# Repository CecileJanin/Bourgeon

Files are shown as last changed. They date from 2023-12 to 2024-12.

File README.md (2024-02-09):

# Bourgeon - A fully open source SBC based on i.MX6Q

Bourgeon is a single board computer based on [i.MX6Q](https://www.nxp.com/products/processors-and-microcontrollers/arm-processors/i-mx-applications-processors/i-mx-6-processors/i-mx-6quad-processors-high-performance-3d-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), a quad-core arm cortex A9 processor with 2Go of DDR3 RAM.
This project has been realised for learning purposes only.

_**A developpement board is functionnal, after applying hardware patches.**_

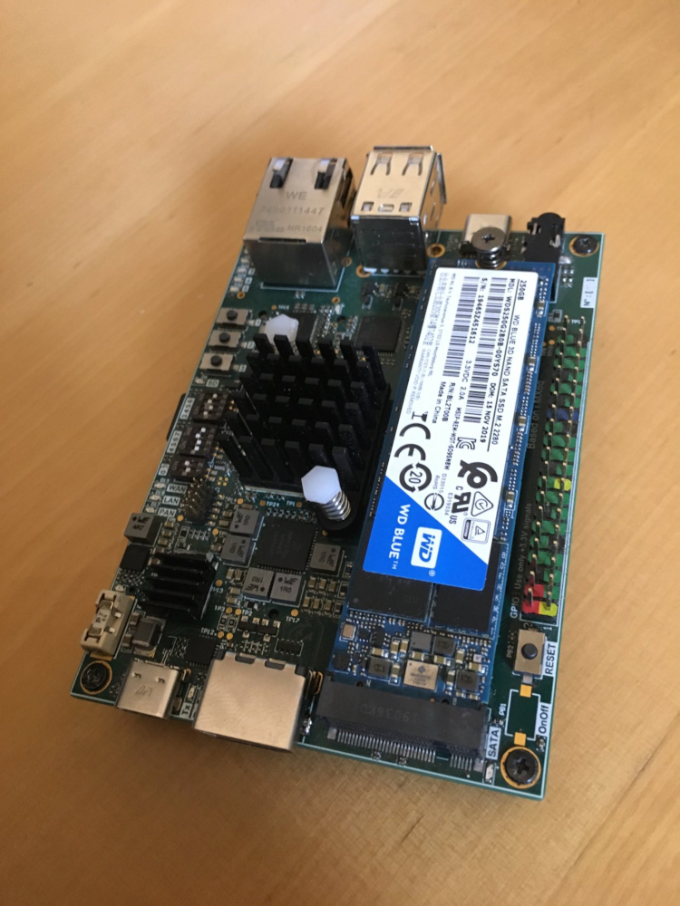
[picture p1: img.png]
bourgeon


## Hardware specification

#### Connectivity :
- 2 USB type A ports
- 1 USB type C OTG port 
- 1 RJ45 10/100/1000 BASE-T ethernet
- 1 M.2 SATA connector 
- 1 SD card slot
- 1 HDMI port
- 1 GPIO raspberry pi compatible connector
- 1 USB type C debug and power port
- 1 mPCIe (with sim card available)
- 1 audio jack 3.5mm
- M.2 non-standard board to board connector, with UART, CAN, SPI, eMMC 8bits, I2C, GPIO...

#### Included memory :
- 8MB Flash NOR via SPI
- 64kB Eeprom via I2C
- 2GB DDR3 RAM 64 bits

## Software

Check boot log file for more detais.

#### Boot

This board uses [u-boot](https://www.denx.de/project/u-boot/), the sources files will be available in src/uboot.

#### linux kernel

The entire board image is under development, and not all hardware is currently supported.

Working and tested :
- RAM
- Sata
- mPCIe
- USB Host
- USB debug
- SD card slot
- Ethernet 10/100/1000BASE-T
- Audio codec SGTL500 
- And some miscellaneous function like DVFS, etc...

## Errata

Criticity level :

1 - Board can't work at all - critical

2 - Board function non-operational

3 - Board or board function must be improved

4 - Minor modification needed

- 1 p7 : Differential main ram clock signals DRAM_CLKO_N inverted 
- 1 global : No boot at ambient temperature, but work perfectly after a warm-up time (1min). Cold boot work (-10°C), but board hangs when the temperature is near 20°C 
- 2 p16 : UART TxD and RxD inverted, debug UART can't work properly
- 2 p16/p5 : USB D+ and D- pin inverted, debug UART can't work properly
- 3 p16 : CP2102N is switched off when the reset PB is pressed. Power supply must be changed to +5V except VIO, must be powered from +3.3V_DEBUG
- 3 global : For a full load, the CPU temperature can rise up to 90°C (too much)
- 3 p16 : CTS and RTS must be functional
- 3 p10 : GPIO wrong power domain, gpio 25, 23, 10, 26 are 2,5V instead of 3.3V
- 3 p8 : Bad phy reference ! No documentation about how to change the output clock from 25MHz to 125MHz, finally found solution on texas forum, but it's a non-standard solution !!! Thanks Ti !  
- 4 p7 : Readability, design note "not used" is at the wrong place
- 4 p1 : Readability, Table of content must be improved, more coherent order, add color...
- 4 p4 : Readability, PMIC schemtic must be more readable
- 4 p7 : Readability, decoupling capacitors name is not readable
- 4 p16 : Need two "No ERC" for U12 p18-19
- 4 global : link between pages (yellow arrows with net name) have no up to date location
- 4 global : Net color must be included in pdf files for more readability
- 4 p18 : R174 is too low, must be 1kOhm
- 4 p16 : usb lanes to usb connector routing pattern must be improved
- 4  global : Change ESD diode for generic 0402 package
- 4 p5 : change 0805 22µF capacitors for same reference as 0603 22µF (lower voltage ratings)
- 4 p2 p9 : Wrong I2C EEPROM addresses
- 4 p2 : Wrong I2C audio codec addresses

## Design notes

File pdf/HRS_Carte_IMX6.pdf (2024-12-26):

Cécile Janin
Travail personnel
cecile.janin@protonmail.com

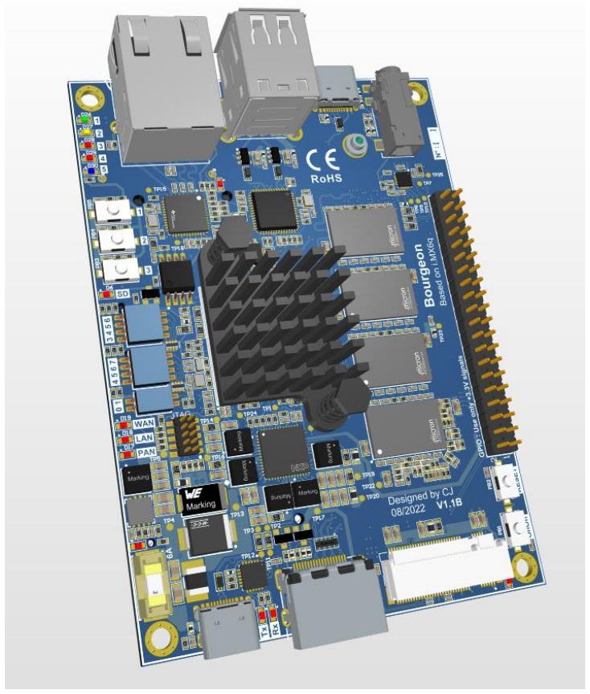
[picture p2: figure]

Projet | Identifiant document | Niveau de sensibilité | Révision
Bourgeon | 001-001-HRS-FR-V1.0 | Ouvert | RA

Spécification de la license (privée, libre, etc)
08/2022 | Page 1 sur 78

# SPECIFICATIONS D’EXIGENCES MATERIELLE (HRS)

# Carte de développement IMX6

SPECIFICATIONS D’EXIGENCES MATERIELLE – CARTE DE DEVELOPPEMENT IMX6

Projet | Identifiant document | Niveau de sensibilité | Révision
Bourgeon | 001-001-HRS-FR-V1.0 | Ouvert | RA

Spécification de la licence (privée, libre, etc)
08/2022 | Page 2 sur 78

# SUIVI DES EVOLUTIONS

## ENREGISTREMENT DES MODIFICATIONS

Version | Date | Auteur.e | Modification
V1.0 | 24/02/2022 | Janin Cécile | Création

V.XX-XX-XX

## APPROBATION

| Nom | Rôle | Date | Signature
Créé ou modifié par | JJ/MM/AAA | NOM Prénom | JJ/MM/AAAA

Vérifié par

Approuvé par

Approuvé par le client si nécessaire

Projet | Identifiant document | Niveau de sensibilité | Révision
Bourgeon | 001-001-HRS-FR-V1.0 | Ouvert | RA
08/2022 | Page 3 sur 78

# LISTE DES ADU / ACU DU DOCUMENT

§ | Numéro de l’exigence | Intitulé de l’ADU / ACU | Description | N° de l’action ou du FT
3.2.2 | -- | Scaling dynamique de la fréquence | Besoin d’un ajout pour le DVFS et drivers associés | 7
1.3 | -- | Schéma | Remplacer les schémas de représentation par plus cohérent à la fin du projet | 1
-- | -- | Approbation | Remplir le tableau d’approbation | 2
8 | -- | Sigles | Remplir les sigles | 3
4.2.3 | -- | Modification | Modifier les exigences de sérigraphie pour l’adresse ip en coordination avec le PCB | 4

Projet | Identifiant document | Niveau de sensibilité | Révision
Bourgeon | 001-001-HRS-FR-V1.0 | Ouvert | RA
08/2022 | Page 4 sur 78

# Table des matières

Projet | Identifiant document | Niveau de sensibilité | Révision
Bourgeon | 001-001-HRS-FR-V1.0 | Ouvert | RA
08/2022 | Page 5 sur 78

Projet | Identifiant document | Niveau de sensibilité | Révision
Bourgeon | 001-001-HRS-FR-V1.0 | Ouvert | RA
08/2022 | Page 6 sur 78

# 1 DOMAINE D’APPLICATION

## 1.1 IDENTIFICATION DE L’ARTICLE

La présente spécification définit les exigences concernant les caractéristiques fonctionnelles et techniques pour l’unique article développé dans le cadre du projet « Bourgeon ».

## 1.2 OBJET DU DOCUMENT

Les exigences spécifiées dans ce document sont :

- Les exigences fonctionnelles
- Relatives aux fonctions hardware
- Les exigences non fonctionnelles :
- Relatives à la fiabilité
- Relatives à la conception et la réalisation
- Relatives à la fonction aptitude au soutien logistique
- Les exigences liées aux caractéristiques physiques et aux interfaces
- Les exigences d’environnements
- Les exigences venant du logiciel

La structure d’une exigence est :

Article_HRS_[num_exigence] Ex : Carte_IMX6_HRS_ [54]

Titre de l’exigence

- Contenu de l’exigence
- …

I/A/D/T (Inspection, Analyse, Démonstration, Test), niveau 1/2/3/4

Fin de l’exigence

Niveaux de vérification :

- 0 : niveau des constituants de l’article
- 1 : niveau de l’article
- 2 : niveau intégration (article interfacé)

Projet | Identifiant document | Niveau de sensibilité | Révision
Bourgeon | 001-001-HRS-FR-V1.0 | Ouvert | RA
08/2022 | Page 7 sur 78
- 3 : niveau de l’article ou système englobant

Une matrice IADT donne, en fin de document, la méthode de vérification des exigences et le niveau de vérification.

## 1.3 GENERALITES SUR L’ARTICLE

Cet article est une carte montée sur entretoises, ayant comme fonction principale le développement et l’apprentissage de l’embarqué basé sur i.MX6 Quad.

Afin de de rendre la carte flexible cette dernière possède de nombreuses entrées / sorties comme le HDMI, de l’USB, des ports GPIO, mais aussi une modularité matérielle notamment liée au connecteur multiple permettant une interface avec une carte fille sur mesure, ainsi qu’aux différentes mémoires embarquées.

Cette carte est dédiée à évoluer dans un environnement intérieur (laboratoire), tout en pouvant être manipulée à la main.

Le système d’exploitation cible de la carte (noyau pilotes, logiciels, etc.) est un OS libre de type GNU/Linux. La phase de R&D utilise la distribution Debian. Cependant, aucune adhérence forte à cette distribution ne doit être introduite afin de permettre l’utilisation d’autres distribution GNU/Linux dans le futur (ArchLinux/ CentOS, etc.).

Projet | Identifiant document | Niveau de sensibilité | Révision
Bourgeon | 001-001-HRS-FR-V1.0 | Ouvert | RA
08/2022 | Page 8 sur 78

# 2 DOCUMENTS

Les documents appelés en référence dans les sections ci-dessous ont le même degré d’applicabilité que les exigences de la présente spécification.

Cette section donne la liste de tous les documents cités en référence dans le présent document.

L’identifiant du document comporte le titre, la source, la référence, la date.

## 2.1 DOCUMENT A APPLIQUER

Cette section précise parmi les documents cités en référence, ceux qui sont à appliquer.

Document | Intitulé | Référence | Date, version

## 2.2 DOCUMENTS DE REFERENCE

Cette section précise les autres documents cités en référence ou dans un autre document, ceux qui peuvent être utilement consultés pour exercer liées au présent document (exemples : documents normatifs, guides, règles de conception, règles de codage)

Document | Intitulé | Référence | Date, version
N1 | Norme IEC sur les décharges électrostatiques – air et contact | IEC/EN 6100-4-2 | 12-09-2008
N2 | Norme ANSI sur la protection du matériel sensible aux décharges électrostatiques | ANSI/ESD S541-2003 | 2003
N3 | Norme IPC sur les classes de PCB | IPC-600 | --
N4 | Norme RoHS – restriction sur les matériaux utilisés | RoHS – 2015/863 | RoHS 3 2015
N5 | Normes environnementales | MIL-STD-810G | 2008 Révision G
N6 | Norme CEM, standard d’émission | IEC 61000-6-3 | --
N7 | Norme connecteur audio jack | OMTP | --
N8 | Acceptabilité des assemblages | IPC-A-610F | Révision F

Projet | Identifiant document | Niveau de sensibilité | Révision
Bourgeon | 001-001-HRS-FR-V1.0 | Ouvert | RA
08/2022 | Page 9 sur 78

électroniques
S1 | Standard mémoire RAM DDR3 | JEDEC79-3E | 07/2010 Révision E
S2 | Standard Ethernet 802.3 | IEEE 802.3 | 2012
S3 | Standard bus USB 2.0 | Universal Serial Bus Specification | 05/2000 Révision 2.0
S4 | Standard mini PCIe | PCI Express-Mini Card Electromechanical Specification | 10/2010 Révision 3.0
S5 | Standard SATA II | Serial ATA revision 3 | 2009 Révision 3
S6 | Standard JTAG | JTAG – IEEE 1149.6 | --
S7 | Standard SATA | Serial ATA | 2009 Révision 3
S8 | Standard HDMI | HMDI standard | 1.4b
S9 | Standard connecteur USB C | Universal serial bus Type C Connectors and cable assemblies compliance document | 2.1b

Projet | Identifiant document | Niveau de sensibilité | Révision
Bourgeon | 001-001-HRS-FR-V1.0 | Ouvert | RA
08/2022 | Page 10 sur 78

# 3 EXIGENCES FONCTIONNELLES

## 3.1 DESCRIPTION GENERALE

Le but de cette section est de fournir des informations sur la constitution de l’article, sur sa fonction ainsi que sur ses interfaces externes.

L’article doit pouvoir accueillir sur un OS libre de type GNU/Linux, et s’interfacer avec d’autres cartes / systèmes de multiples manières différentes, afin de pouvoir expérimenter les capacités de l’IMX6.

Cette carte se constitue de :

- Un connecteur d’alimentation en USB type C, servant également de console de debug
- Une interface HDMI
- Des connecteurs d’extension carte à carte comprenant :
- Un connecteur mini PCIe
- Un connecteur SATA M.2
- Un slot pour cartes micro SD
- Un connecteur multi-interfaces, dédié à la mise en place d’un carte fille dédiée
- De la mémoire soudée
- Une EEPROM, pouvant contenir un bootloader, ou autre
- Une mémoire flash, pouvant contenir le bootloader ou autre
- De la mémoire RAM, dédiée à l’IMX6
- Une interface Ethernet
- Une entrée/sortie audio analogique
- Une interface utilisateur, composée de :
- Trois boutons poussoirs
- 5 LEDs
- Un bouton power, pour allumer / éteindre la carte
- Des ports USB Host et OTG

Scénarios d’utilisation :

- Un serveur MQTT
- Ajout d’une carte fille contenant un module radio LoRa, pour de la communication longue distance
- Ajout d’une carte fille contenant un système de recharge de batterie, rendant la carte autonome

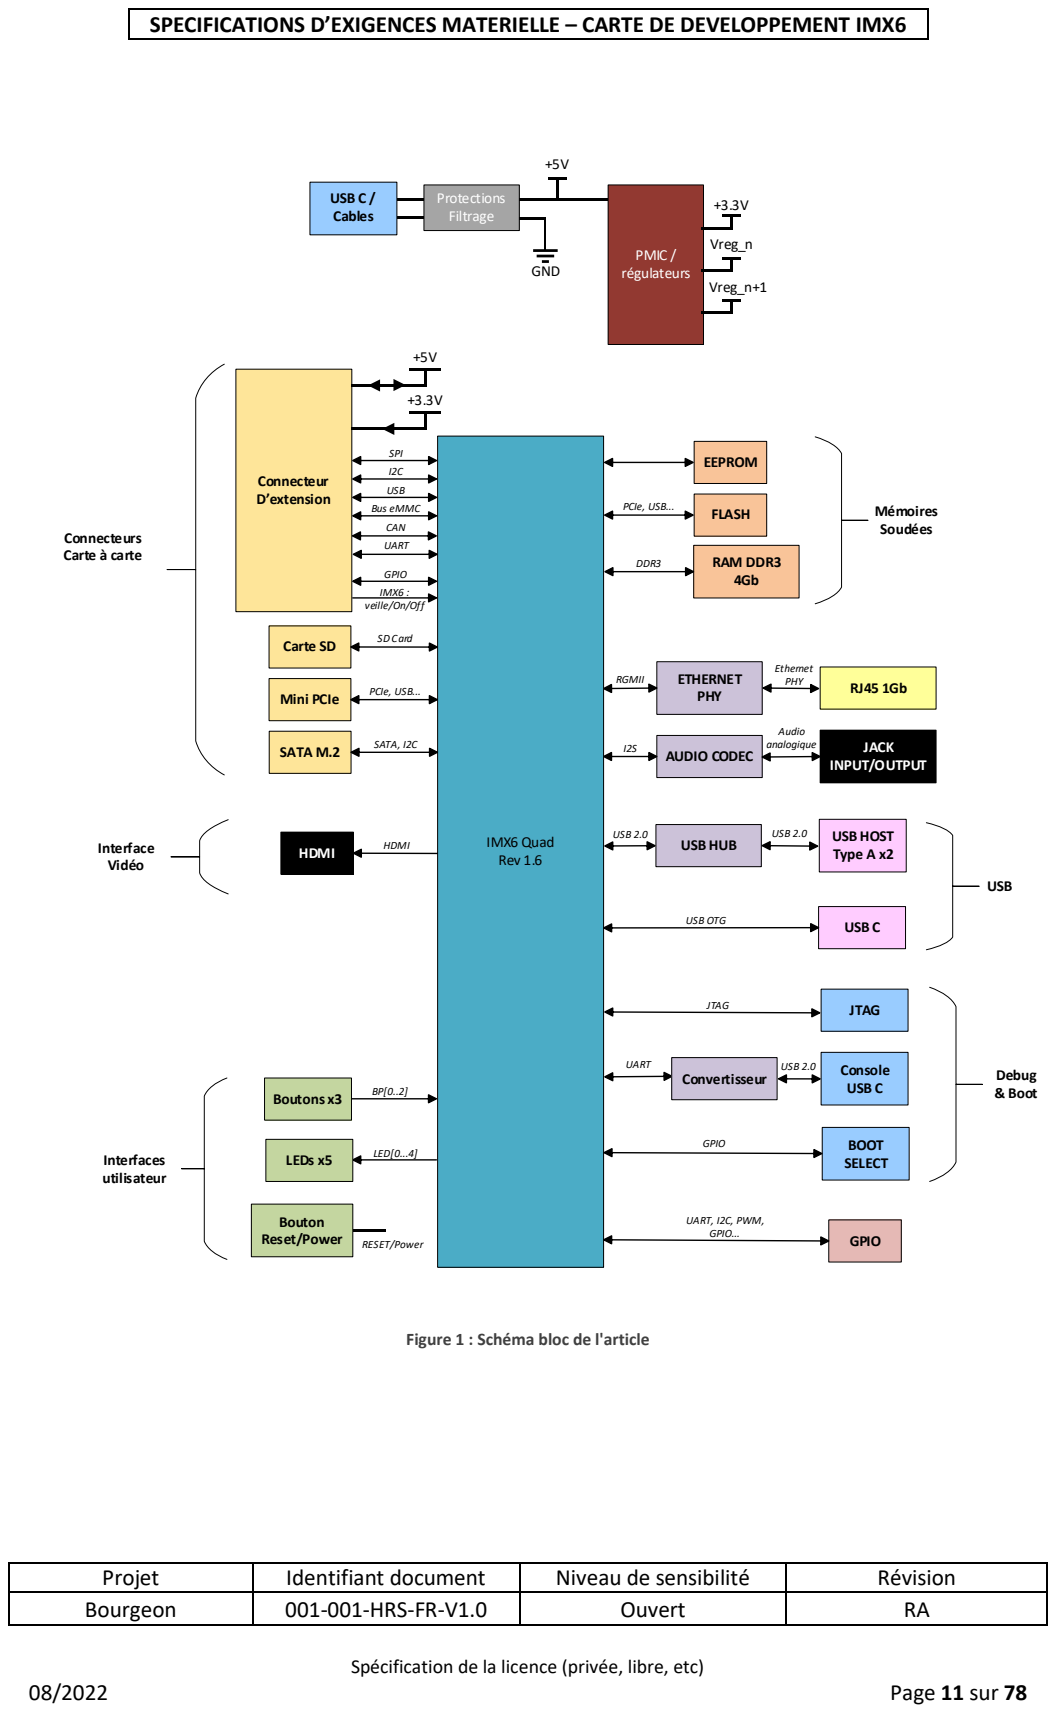
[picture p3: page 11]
Page 11 sur 78; Protections Filtrage; GND; PMIC / régulateurs; Vreg_n; HDMI; Carte SD; SD Card; Mini PCIe; PCIe, USB...; SATA M.2; SATA, I2C; USB; Connecteur D extension; EEPROM; RAM DDR3 4Gb; Connecteurs Carte à carte; Bus eMMC; GPIO; SPI; IMX6 : veille/On/Off; CAN; Vreg_n+1; ETHERNET PHY; AUDIO CODEC I2S; RGMII; Ethernet PHY; DDR3; JACK INPUT/OUTPUT; Audio analogique; IMX6 Quad Rev 1.6; LED[0...4]; RESET/Power; Interfaces utilisateur; JTAG; Console USB C; UART; Convertisseur; Interface Vidéo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

FLASH PCIe, USB...

USB C USB OTG

Figure 1 : Schéma bloc de l'article

Projet | Identifiant document | Niveau de sensibilité | Révision
Bourgeon | 001-001-HRS-FR-V1.0 | Ouvert | RA

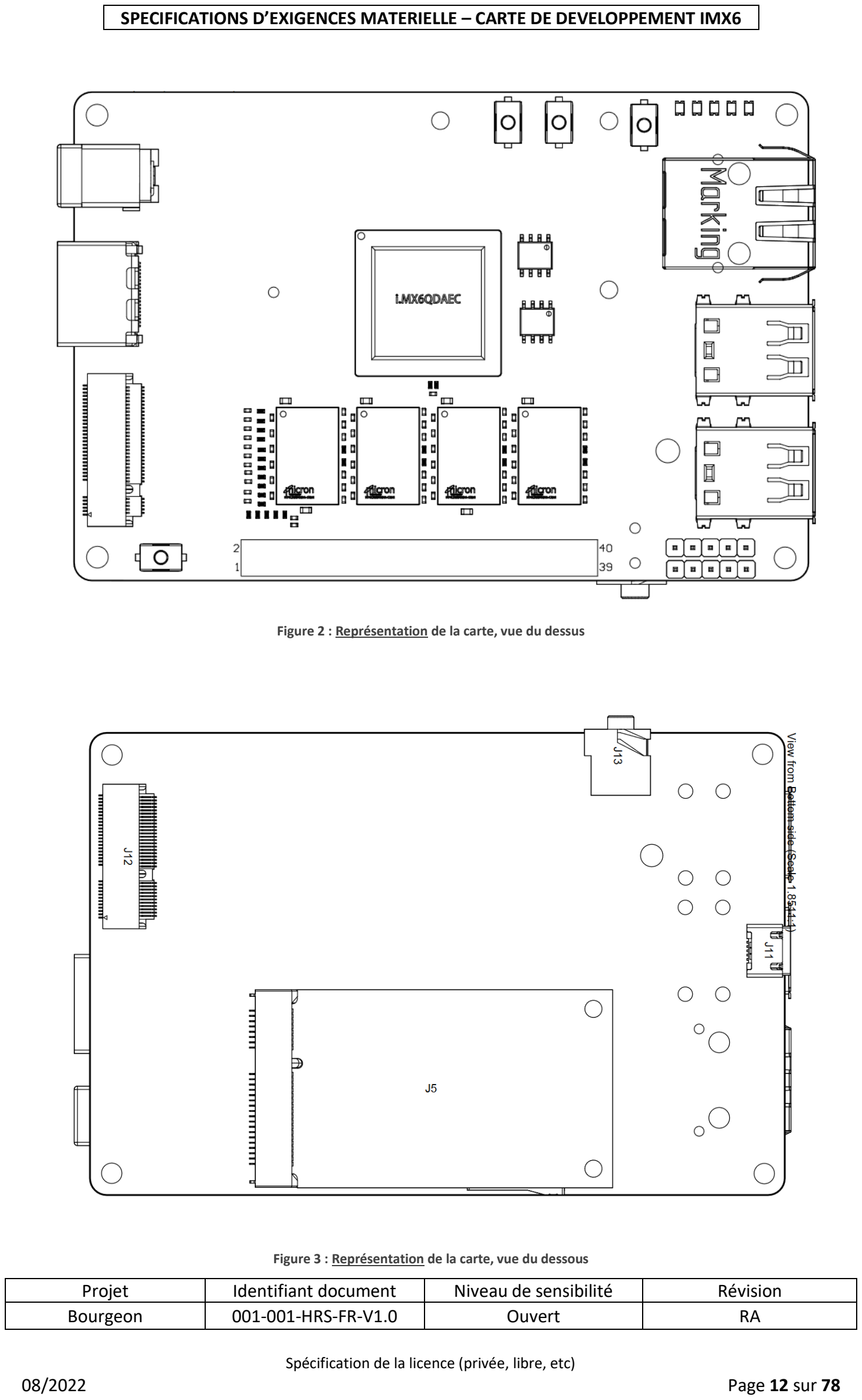
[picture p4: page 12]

Projet | Identifiant document | Niveau de sensibilité | Révision
Bourgeon | 001-001-HRS-FR-V1.0 | Ouvert | RA
08/2022 | Page 12 sur 78

Figure 2 : Représentation de la carte, vue du dessus

Figure 3 : Représentation de la carte, vue du dessous

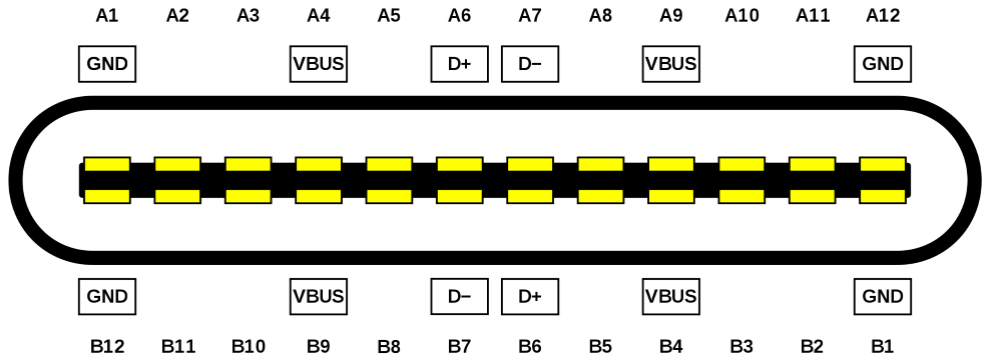
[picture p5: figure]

Projet | Identifiant document | Niveau de sensibilité | Révision
Bourgeon | 001-001-HRS-FR-V1.0 | Ouvert | RA
08/2022 | Page 13 sur 78

## 3.2 CRACTERISTIQUES HARDWARE

Cette section identifie chacune des fonctions hardware requises du module et détaille les spécifications associées à chacune de ces fonctions.

3.2.1 ALIMENTATION

Carte_IMX6_HRS_ [1]

Description connecteur d’alimentation de la carte

- Le connecteur d’alimentation doit être un port USB type C femelle selon le standard [S9]
- Des câbles d’alimentation doivent pouvoir être soudés
- Une LED rouge visible depuis le dessus de la carte doit s’allumer en cas de présence de tension

Inspection, niveau 1

Fin de l’exigence

Carte_IMX6_HRS_ [2]

Caractéristiques électriques connecteur d’entrée

- La tension d’entrée doit être une tension continue de 5V
- L’entrée d’alimentation doit être protégée contre les courts-circuits francs internes via un fusible

Test, niveau 1

Projet | Identifiant document | Niveau de sensibilité | Révision
Bourgeon | 001-001-HRS-FR-V1.0 | Ouvert | RA
08/2022 | Page 14 sur 78

Fin de l’exigence

Carte_IMX6_HRS_ [3]

Protection connecteur d’entrée

- L’entrée d’alimentation doit résister à des décharges électrostatiques de niveau 3 selon la norme [N1]

Test, niveau 1

Fin de l’exigence

Carte_IMX6_HRS_ [4]

Mesure du courant des tensions régulées en interne de la carte

- Le courant de toutes les tensions internes à la carte doit pouvoir être mesuré aux bornes de résistances de shunt situées sur le rail de tension positif (Ex : résistance de 20mOhm sur le +5V)

Inspection, niveau 1

Fin de l’exigence

Carte_IMX6_HRS_ [5]

Rendements régulateurs

- Aucun régulateur ne doit dépasser la température de 60°C (pleine charge, 25°C ambiant)

Test, niveau 1

Fin de l’exigence

3.2.2 PROCESSEUR

Projet | Identifiant document | Niveau de sensibilité | Révision
Bourgeon | 001-001-HRS-FR-V1.0 | Ouvert | RA
08/2022 | Page 15 sur 78

Carte_IMX6_HRS_ [6]

Caractéristiques processeur IMX6

- La carte doit être peuplée par un IMX6 Quad
- L’empreinte de l’IMX6 doit être du FPBGA 25*25, avec un pitch de 0.8mm
- La version matérielle de l’IMX6 doit être la Rev 1.6
- La fréquence maximale de l’IMX6 doit être d’au moins 950MHz

Inspection, niveau 1

Fin de l’exigence

Carte_IMX6_HRS_ [7]

Dissipateur IMX6

- La carte doit comporter un emplacement non peuplé pour un dissipateur thermique à convection naturelle

Inspection, niveau 1

Fin de l’exigence

Projet | Identifiant document | Niveau de sensibilité | Révision
Bourgeon | 001-001-HRS-FR-V1.0 | Ouvert | RA
08/2022 | Page 16 sur 78

Carte_IMX6_HRS_ [8]

Watchdog IMX6

- L’IMX6 doit pouvoir être redémarré par son watchdog hardware.

Inspection, niveau 1

Fin de l’exigence

Carte_IMX6_HRS_ [9]

Tenue de charge IMX6

- L’IMX6 doit pouvoir fonctionner au maximum de ses capacités de calcul (tous les cœurs à 100% d’utilisation) de manière continue

Démonstration, niveau 1

Fin de l’exigence

Projet | Identifiant document | Niveau de sensibilité | Révision
Bourgeon | 001-001-HRS-FR-V1.0 | Ouvert | RA
08/2022 | Page 17 sur 78

Carte_IMX6_HRS_ [10]

Température IMX6

- La température de l’IMX6 doit se maintenir sous 60°C (pleine charge, 25°C ambiant)

Démonstration, niveau 1

Fin de l’exigence

3.2.3 BOOT

Carte_IMX6_HRS_ [11]

Sélecteur de boot IMX6

- La carte IMX6 doit comporter des interrupteurs sur le pcb qui doivent permettre la sélection du périphérique utilisé pour le mode boot.

Inspection, niveau 1

Fin de l’exigence

Carte_IMX6_HRS_ [12]

Périphérique de boot

- L’IMX6 doit pouvoir booter en utilisant le bootloader contenu dans :
- La Flash NOR
- Le SSD
- La carte SD
- L’eMMC (connecteur d’extension)

Démonstration, niveau 1

Fin de l’exigence

Carte_IMX6_HRS_ [13]

Sélections de boot IMX6

- Les périphériques pouvant être sélectionnés pour le boot doivent être :
- La Flash NOR
- Le SSD
- La carte SD

Projet | Identifiant document | Niveau de sensibilité | Révision
Bourgeon | 001-001-HRS-FR-V1.0 | Ouvert | RA
08/2022 | Page 18 sur 78
- L’eMMC (connecteur d’extension, voir section dédiée)

Inspection, niveau 1

Fin de l’exigence

Carte_IMX6_HRS_ [14]

Mise sous tension

- Lors de la mise sous tension, La carte doit booter d’elle-même

Démonstration, niveau 1

Fin de l’exigence

3.2.4 MEMOIRES SOUDEES

Cette partie traite des différentes mémoires disponibles sur la carte IMX6.

3.2.4.1 RAM

Carte_IMX6_HRS_ [15]

Caractéristiques mémoire RAM

- La mémoire RAM doit être de type DDR3 respectant le standard [S1]
- La mémoire RAM doit être interfacée avec l’IMX6 via un bus de 64 bits
- La mémoire RAM doit avoir une fréquence d’échange processeur d’au moins 800MHz et maximum de maximum 1066MHz
- La mémoire RAM doit avoir une capacité de 4Gb

Analyse, niveau 1

Fin de l’exigence

Projet | Identifiant document | Niveau de sensibilité | Révision
Bourgeon | 001-001-HRS-FR-V1.0 | Ouvert | RA
08/2022 | Page 19 sur 78

Carte_IMX6_HRS_ [16]

Performance Mémoire RAM

- Le débit de la mémoire RAM doit être de 6Gb/s minimum hors temps de rafraichissement
- Le temps t_CAS doit être de 15 t_clock maximum

Test, niveau 1

Fin de l’exigence

IMX6 Quad | RAM DDR3 4Gb

Bus DDR 64bits

Figure 4 : Interface RAM DDR3 avec l’IMX6

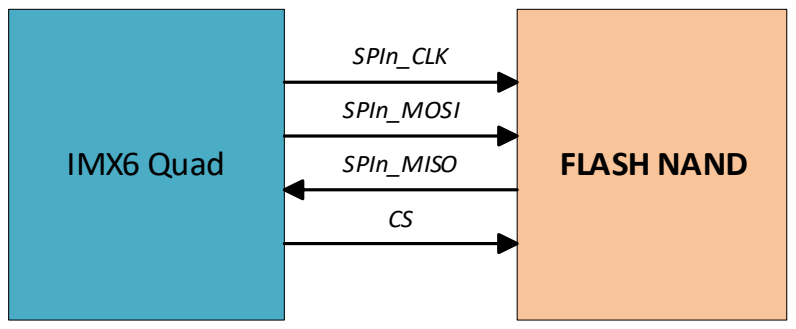
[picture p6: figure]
IMX6 Quad; FLASH NAND; SPIn_CLK; SPIn_MOSI; SPIn_MISO

Projet | Identifiant document | Niveau de sensibilité | Révision
Bourgeon | 001-001-HRS-FR-V1.0 | Ouvert | RA
08/2022 | Page 20 sur 78

3.2.4.2 Flash NOR

Carte_IMX6_HRS_ [17]

Caractéristiques mémoire Flash

- La mémoire Flash doit être interfacée avec l’IMX6 via un bus SPI
- La mémoire Flash doit avoir une capacité de 64Mb

Inspection, niveau 0

Fin de l’exigence

Carte_IMX6_HRS_ [18]

Performance mémoire FLASH

- La vitesse de lecture et d’écriture minimale de la mémoire flash doit être de 1Mo/s

Démonstration, niveau 1

Fin de l’exigence

Carte_IMX6_HRS_ [19]

Rétention mémoire FLASH

- La rétention de données doit être d’au moins 10 ans

Analyse, niveau 0

Fin de l’exigence

Projet | Identifiant document | Niveau de sensibilité | Révision
Bourgeon | 001-001-HRS-FR-V1.0 | Ouvert | RA
08/2022 | Page 21 sur 78

Figure 5 : Interface Flash avec l’IMX6
3.2.4.3 EEPROM

La mémoire EEPROM peut servir à contenir le bootloader ou juste des données, selon utilisation.

Carte_IMX6_HRS_ [20]

EEPROM

- L’EEPROM doit être interfacée avec l’IMX6
- L’EEPROM doit être dans un boitier facilement remplaçable à l’aide d’air chaud

Inspection, niveau 1

Fin de l’exigence

IMX6 Quad | EEPROM

I2Cn_SDA

I2Cn_SCL

Figure 6 : Interface de l'EEPROM avec l'IMX6

Carte_IMX6_HRS_ [21]

Capacité EEPROM

- L’EEPROM doit avoir une capacité de 512ko

Inspection, niveau 1

Fin de l’exigence

Projet | Identifiant document | Niveau de sensibilité | Révision
Bourgeon | 001-001-HRS-FR-V1.0 | Ouvert | RA
08/2022 | Page 22 sur 78

Carte_IMX6_HRS_ [22]

Performance EEPROM

- La vitesse de lecture et d’écriture minimale de l’EEPROM doit être de 20kb/s

Test, niveau 1

Fin de l’exigence

Carte_IMX6_HRS_ [23]

Rétention EEPROM

- La rétention de données doit être d’au moins 10 ans

Analyse, niveau 0

Fin de l’exigence

Projet | Identifiant document | Niveau de sensibilité | Révision
Bourgeon | 001-001-HRS-FR-V1.0 | Ouvert | RA
08/2022 | Page 23 sur 78

3.2.5 INTERFACES

3.2.5.1 Ethernet

Carte_IMX6_HRS_ [24]

Caractéristiques interface Ethernet

- L’article doit avoir un port Ethernet interfacé avec l’IMX6
- L’interface Ethernet doit être conforme au standard [S2], 10BASE-T, 100BASE-T, 1000BASE-T
- L’activité Rx de l’interface Ethernet doit être visible via une LED orange, et en cas de connexion établie (link up) une LED verte doit s’allumer. Les deux LEDs doivent être intégrées au connecteur RJ45
- L’interface Ethernet doit supporter l’autonégociation telle que spécifiée dans la norme [S2]

Inspection, niveau 1

Fin de l’exigence

Carte_IMX6_HRS_ [25]

Performance interface Ethernet

- L’interface Ethernet doit atteindre un débit d’au moins 200Mb/s en 1000BASE-T, montant et descendant en simultané

Test, niveau 2

Fin de l’exigence

Carte_IMX6_HRS_ [26]

Protections de l’interface Ethernet

- L’interface Ethernet doit supporter des décharges ESD conformément à la norme [N1] niveau 3

Test, niveau 1

Fin de l’exigence

Projet | Identifiant document | Niveau de sensibilité | Révision
Bourgeon | 001-001-HRS-FR-V1.0 | Ouvert | RA
08/2022 | Page 24 sur 78

Figure 7 : Interface Ethernet avec l'IMX6

3.2.5.2 USB HOST

Carte_IMX6_HRS_ [27]

Caractéristiques USB HOST

- La carte doit comporter 2 ports USB HOST avec des connecteurs type USB A (femelle)
- Les ports USB doivent être conformes à la norme [N2]
- Les ports USB doivent être interfacés avec l’IMX6, avec ou sans HUB USB

Inspection, niveau 1

Fin de l’exigence

Carte_IMX6_HRS_ [28]

Alimentation USB HOST

- Les ports USB doivent fournir une tension de 5V ±0.25V (selon charge) sous 500mA maximum (par port)

Test, niveau 1

Fin de l’exigence

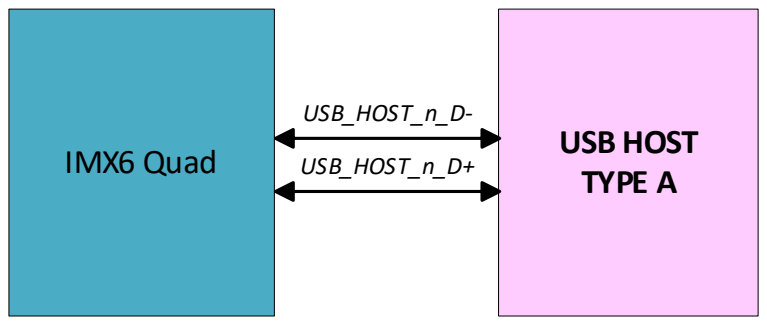
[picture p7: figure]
IMX6 Quad; USB HOST; TYPE A; USB_HOST_n_D-; USB_HOST_n_D+
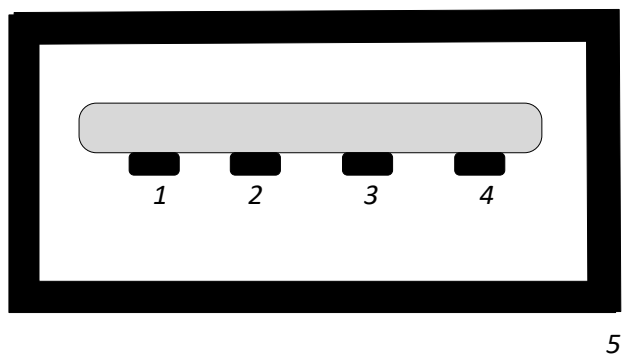
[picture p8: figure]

Projet | Identifiant document | Niveau de sensibilité | Révision
Bourgeon | 001-001-HRS-FR-V1.0 | Ouvert | RA
08/2022 | Page 25 sur 78

Carte_IMX6_HRS_ [29]

Protections USB HOST

- Les ports USB doivent supporter des décharges ESD conformément à la norme [N1] niveau 3
- L’alimentation des ports USB doit être individuellement protégée contre les courts circuits externes. Cela doit prendre la forme d’une limitation de courant à 500mA ±50mA, puis coupure de l’alimentation après 50 ms ±10ms de court-circuit.

Test, niveau 1

Fin de l’exigence

Figure 8 : Interface de l'USB HOST avec l'IMX6

Projet | Identifiant document | Niveau de sensibilité | Révision
Bourgeon | 001-001-HRS-FR-V1.0 | Ouvert | RA
08/2022 | Page 26 sur 78
Broche | Type | Description
N° | Nom
1 | +5V_USB_HOST _n | POWER | Alimentation USB
2 | USB_HOST_n_D- | I/O | Signal USB, n le numéro du port, 90 Ohm ±10%
| USB_HOST_n_D+ | I/O | différentiel 3
4 | GND | POWER | Masse
5 | USB_HOST_SHELL | - | Connection du châssis

3.2.5.3 USB OTG

Carte_IMX6_HRS_ [30]

Caractéristiques USB OTG

- La carte doit comporter 1 ports USB OTG avec un connecteur type USB micro femelle
- Le port USB doit être conforme à la norme [N2]
- Le port USB OTG doit être interfacé avec l’IMX6
- L’alimentation du port OTG ne doit pas alimenter la carte

Inspection, niveau 1

Fin de l’exigence

Carte_IMX6_HRS_ [31]

Protections USB OTG

- Le port USB doit supporter des décharges ESD conformément à la norme [N1] niveau 3

Test, niveau 1

Fin de l’exigence

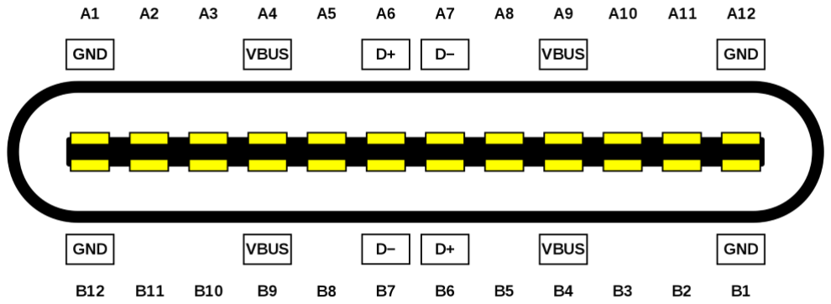
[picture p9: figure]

Projet | Identifiant document | Niveau de sensibilité | Révision
Bourgeon | 001-001-HRS-FR-V1.0 | Ouvert | RA
08/2022 | Page 27 sur 78 IMX6 Quad | USB OTG

Figure 9 : Interface de l'USB OTG avec l'IMX6

Figure 10 : Brochage connecteur OTG

Broche | Type | Description
N° | Nom
A1 | GND | | Masse
A6 | USB_OTG_D_P | I/O | Bus USB, paires différentielles, mêmes que B6-7
A7 | USB_OTG_D_N | I/O

Projet | Identifiant document | Niveau de sensibilité | Révision
Bourgeon | 001-001-HRS-FR-V1.0 | Ouvert | RA
08/2022 | Page 28 sur 78
Broche | Type | Description
N° | Nom
A12 | GND | | Masse
B1 | GND | | Masse
B6 | USB_OTG_D_P | I/O | Bus USB, paires différentielles, mêmes que A6-7
B7 | USB_OTG_D_N | I/O
B12 | GND | | Masse

3.2.5.4 Audio

Carte_IMX6_HRS_ [32]

Caractéristiques entrée/sortie audio

- La carte doit disposer d’un connecteur femelle entrée/sortie audio analogique
- Le connecteur doit être un jack 3.5mm de diamètre, 4 segments : masse, L, R, MIC, respectant la norme [N7]

Inspection, niveau 1

Fin de l’exigence

Carte_IMX6_HRS_ [33]

Performance entrée/sortie audio

- L’encodage de la sortie audio doit se faire sous 16 bits ou plus avec une fréquence d’échantillonnage de 44.1kHz minimum
- La sortie audio doit avoir une puissance de sortie de 10mW minimum sous 16ohm de charge à 1kHz
- L’encodage de l’entrée audio doit se faire sous 16 bits avec une fréquence d’échantillonnage de 44.1kHz minimum

Inspection, niveau 0

Fin de l’exigence

Projet | Identifiant document | Niveau de sensibilité | Révision
Bourgeon | 001-001-HRS-FR-V1.0 | Ouvert | RA
08/2022 | Page 29 sur 78

Carte_IMX6_HRS_ [34]

Protection entrée/sortie audio

- L’interface audio doit supporter des décharges ESD conformément à la norme [N1] niveau 3

Test, niveau 1

Fin de l’exigence

Broche | Type | Description
N° | Nom
1 | GND | | Masse
2 | LEFT | O | Haut-parleur gauche
3 | RIGHT | O | Haut-parleur droit
4 | MIC | I | Entrée microphone

Projet | Identifiant document | Niveau de sensibilité | Révision
Bourgeon | 001-001-HRS-FR-V1.0 | Ouvert | RA
08/2022 | Page 30 sur 78

3.2.5.5 Mini PCIe

Carte_IMX6_HRS_ [35]

Caractéristiques mini PCIe

- La carte doit comporter un connecteur mini PCIe conforme au standard [S4]
- Le connecteur mini PCIe doit être interfacé avec l’IMX6
- Le socket présent sur la carte IMX6 doit pouvoir accueillir des facteurs de forme pleins ou réduits de moitié (Voir [S4] page 12-13)
- Le connecteur mini PCIe doit être interfacé à un slot UIM (SIM) via les broches dédiées.

Inspection, niveau 1

Fin de l’exigence

Carte_IMX6_HRS_ [36]

Performance mini PCIe

- Le débit de l’interface PCIe doit être de 400Mo/s montant et descendant, en simultané

Test, niveau 1

Fin de l’exigence

Carte_IMX6_HRS_ [37]

Alimentation mini PCIe

- L’alimentation +3.3V du mini PCIe doit fournir un courant maximal de 1A, et 100mA pour le +1.5V

Test, niveau 1

Fin de l’exigence

Projet | Identifiant document | Niveau de sensibilité | Révision
Bourgeon | 001-001-HRS-FR-V1.0 | Ouvert | RA
08/2022 | Page 31 sur 78 IMX6 Quad | Mini PCIe PCIe, USB...

Figure 11 : Interface du PCIe avec l'IMX6

Côté 1

Broche | Type | Description
N° | Nom
1 | PCIe_WAKE# | O | Broche en drain ouvert, actif à l’état bas.
3 | PCIe_COEX1 | I/O | Coexistence avec d’autres cartes ; Non utilisées.
5 | PCIe_COEX2 | I/O
7 | PCIe_CLKREQ# | O | Horloge de référence (requête) ; non utilisé
9 | GND | | Masse
11 | PCIe_REFCLK_N | I | Horloge de référence du PCIe, 100MHz, 100Ohm ±10% différentiel
13 | PCIe_REFCLK_P | I
15 | GND | | Masse

Détrompeur

17 | Réservé (UIM_C8) | | Broches supplémentaires pour l’UIM. Ne pas connecter
19 | Réservé (UIM_C4)
21 | GND | | Masse
23 | PCIe_TX_N | I/O | Signaux de données – réception, 100Ohm ±10% différentiel
25 | PCIe_TX_P | I/O
27 | GND | | Masse
29 | GND | | Masse
31 | PCIe_RX_N | I/O | Signaux de données – émission, 100Ohm ±10% différentiel
33 | PCIe_RX_P | I/O
35 | GND | | Masse
37 | GND | | Masse

Projet | Identifiant document | Niveau de sensibilité | Révision
Bourgeon | 001-001-HRS-FR-V1.0 | Ouvert | RA
08/2022 | Page 32 sur 78
39 | +3.3V_PCIe | I | Alimentation du PCIe, +3.3V ±0.1V 1A
41 | +3.3V_PCIe | I | Alimentation du PCIe, +3.3V ±0.1V 1A
43 | GND | | Masse
45 | RESERVED
| RESERVED | | Ne pas connecter 47
49 | RESERVED
51 | RESERVED

Côté 2

Broche | Type | Description
N° | Nom
2 | +3.3V_PCIe | I | Alimentation du PCIe, +3.3V ±0.1V 1A
4 | GND | | Masse
6 | +1.5V_PCIe | I | Alimentation du PCIe, +1.5V ±0.05V, 100mA
8 | PCIe_UIM_PWR | O | Alimentation pour l’UIM
10 | PCIe_UIM_DATA | I/O | Signaux d’information pour l’UIM
12 | PCIe_UIM_CLK | O | Signal d’horloge pour l’UIM
14 | PCIe_UIM_RESET | O | Signal de RESET pour l’UIM
16 | PCIe_UIM_VPP | O | Tension d’alimentation variable

Détrompeur

18 | GND
20 | PCIe_W_DISABLE# | I | Actif bas, utilisé pour désactiver l’émission radio de la carte
22 | PCIe_PERST# | O | Actif bas, utilisé pour un reset fonctionnel de la carte
24 | PCIe_+3.3V_AUX | I | Alimentation du PCIe, +3.3V ±0.1V 1A
26 | GND
28 | +1.5V_PCIe | I | Alimentation du PCIe, +1.5V ±0.05V, 100mA

Projet | Identifiant document | Niveau de sensibilité | Révision
Bourgeon | 001-001-HRS-FR-V1.0 | Ouvert | RA
08/2022 | Page 33 sur 78
30 | PCIe_SMB_CLK | O | Signaux horloge et information du SMBUS
| PCIe_SMB_DATA | I/O | Broches compatibles +3.3V 32
34 | GND
36 | PCIe_USB_D- | I/O | Signaux USB
38 | PCIe_USB_D+ | I/O
40 | GND | | Masse
42 | PCIe_LED_WWAN# | O
| PCIe_LED_WLAN# | O | Drain ouvert, actif bas. Sert d’indicateur de statuts à la carte PCIe 44
46 | PCIe_LED_WPAN# | O
48 | +1.5V_PCIe | I | Alimentation du PCIe, +1.5V ±0.05V, 100mA
50 | GND | | Masse
52 | +3.3V_PCIe | I | Alimentation du PCIe, +3.3V ±0.1V 1A

3.2.5.6 JTAG

Carte_IMX6_HRS_ [38]

Caractéristiques JTAG

- La carte doit comporter une interface JTAG, connectée à l’IMX6
- Le connecteur doit être composé de broches simples (headers), avec un pas de 1.27mm en 2 rangées de 5 broches chacune
- Le connecteur doit être compatible avec le connecteur GW16099 de chez GateWorks, sans le UART
- L’interface doit être compatible 3.3V

Inspection, niveau 1

Fin de l’exigence

Carte_IMX6_HRS_ [39]

Protections JTAG

- L’interface JTAG doit supporter des décharges ESD conformément à la norme [N1] niveau 3

Inspection, niveau 1

Fin de l’exigence

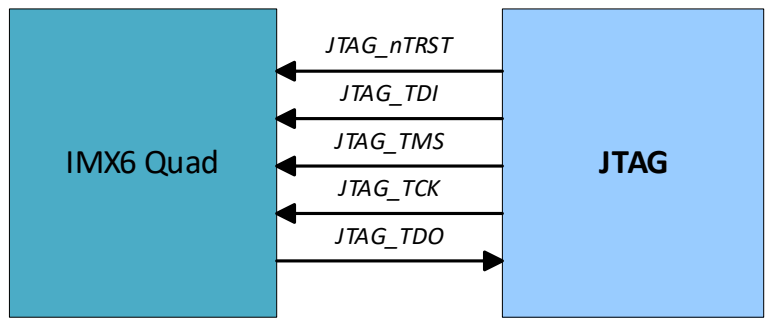
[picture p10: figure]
JTAG_nTRST; JTAG_TDI; JTAG_TMS; JTAG_TCK; JTAG_TDO
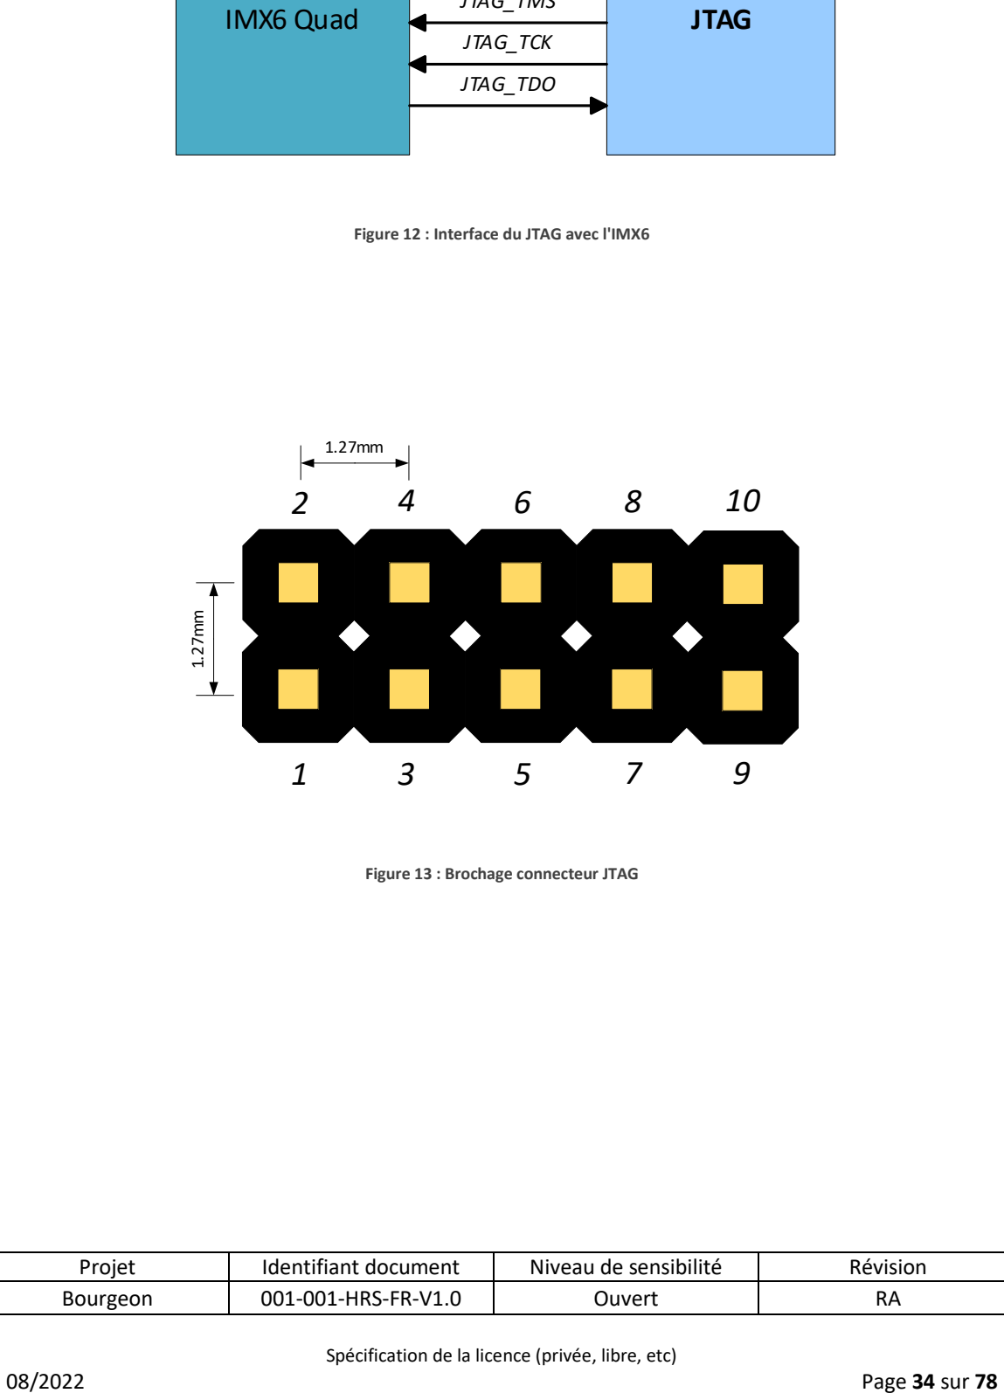
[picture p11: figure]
Projet; Identifiant document; Niveau de sensibilité; Révision; Bourgeon; 001-001-HRS-FR-V1.0; Ouvert; Page 34 sur 78 IMX6 Quad; JTAG; Figure 13 : Brochage connecteur JTAG

Figure 12 : Interface du JTAG avec l'IMX6

Projet | Identifiant document | Niveau de sensibilité | Révision
Bourgeon | 001-001-HRS-FR-V1.0 | Ouvert | RA
08/2022 | Page 35 sur 78
Broche | Type | Niveau de tension | Description
N° | Nom | | Haut
1 | JTAG_nTRST | O | +3.3V | Reset du JTAG
2 | VCC_JTAG | I | | Tension de référence du JTAG
3 | JTAG_TDI | O | | Données entrant dans la cible
4 | GND | | | Masse
5 | JTAG_TMS | O | | Signal de mode d’entrée de la cible
6 | N.C | | | Ne pas connecter
7 | JTAG_TCK | O | | Signal d’horloge envoyé à la cible
8 | N.C | | | Ne pas connecter
9 | JTAG_TDO | I | | Données venant de la cible
10 | N.C | | | Ne pas connecter

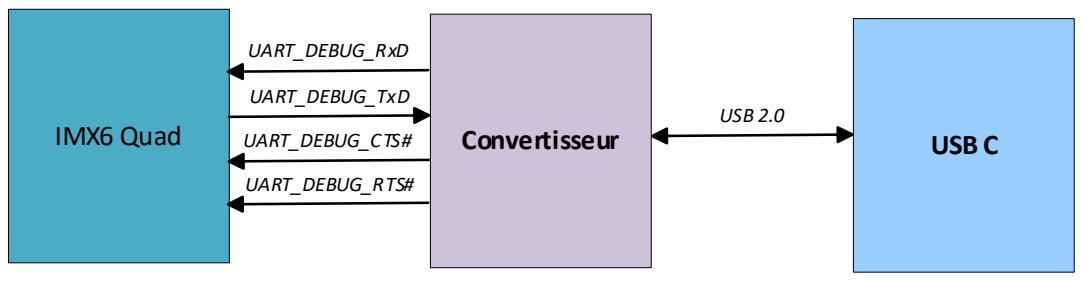
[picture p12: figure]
IMX6 Quad; Convertisseur; USB C; UART_DEBUG_RxD; UART_DEBUG_TxD; UART_DEBUG_CTS#; UART_DEBUG_RTS#; USB 2.0

Projet | Identifiant document | Niveau de sensibilité | Révision
Bourgeon | 001-001-HRS-FR-V1.0 | Ouvert | RA
08/2022 | Page 36 sur 78

3.2.5.7 UART (console)

Carte_IMX6_HRS_ [40]

Caractéristique interface UART (console)

- La carte doit comporter une interface de console debug disponible via un bus USB 2.0 suivant la norme [S3]
- Le connecteur doit être de l’USB type C suivant le standard [S9]

Inspection, niveau 1

Fin de l’exigence

Carte_IMX6_HRS_ [41]

Protection interface UART

- Le connecteur doit supporter des décharges ESD conformément à la norme [N1] niveau 3

Test, niveau 1

Fin de l’exigence

Figure 14 : Interface UART console avec l'IMX6

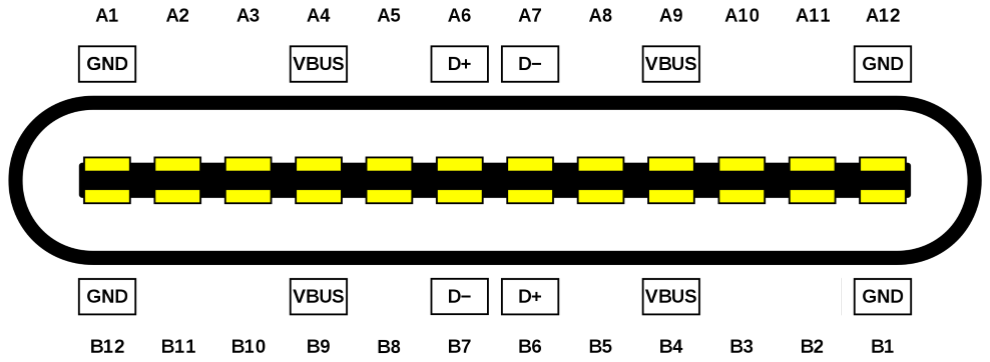
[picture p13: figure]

Projet | Identifiant document | Niveau de sensibilité | Révision
Bourgeon | 001-001-HRS-FR-V1.0 | Ouvert | RA
08/2022 | Page 37 sur 78

Figure 15 : Brochage port USB C

3.2.5.8 Serial ATA M.2

Carte_IMX6_HRS_ [42]

Norme SATA

- L’interface SATA doit être conforme à la norme [N7]

Inspection, niveau 1

Fin de l’exigence

Carte_IMX6_HRS_ [43]

Connecteur SATA

- Le connecteur doit être un connecteur m.2 SATA avec une clé détrompeuse type M
- Un disque SSD de format 2280 doit pouvoir être mis en place, avec des composants des deux côtés

Inspection, niveau 1

Fin de l’exigence

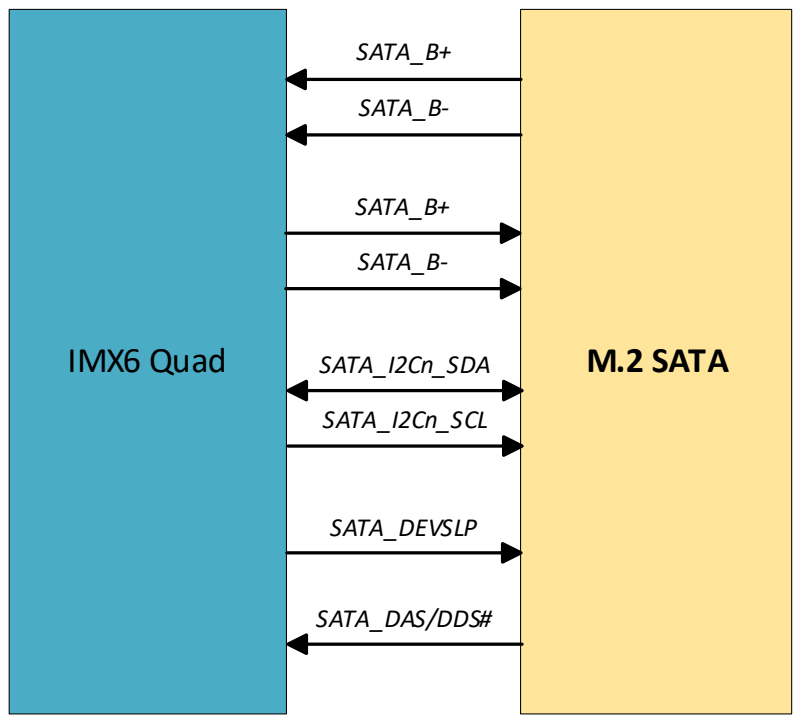
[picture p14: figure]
IMX6 Quad; M.2 SATA; SATA_B+; SATA_B-; SATA_I2Cn_SDA; SATA_I2Cn_SCL; SATA_DEVSLP; SATA_DAS/DDS#

Projet | Identifiant document | Niveau de sensibilité | Révision
Bourgeon | 001-001-HRS-FR-V1.0 | Ouvert | RA
08/2022 | Page 38 sur 78

Figure 16 : Interface du SATA avec l'IMX6

Côté 1

Broche | Type | Niveau de tension Haut | Description
N° | Nom

Projet | Identifiant document | Niveau de sensibilité | Révision
Bourgeon | 001-001-HRS-FR-V1.0 | Ouvert | RA
08/2022 | Page 39 sur 78
1 | SATA_CONFIG3 | I | Connecter à la masse
3 | GND | | Masse
5 | Réservé | | Ne pas connecter
7 | Réservé | | Ne pas connecter
9 | Réservé | | Ne pas connecter
11 | Réservé | | Ne pas connecter

Détrompeur

21 | SATA_CONFIG0 | I | Connecter à la masse
23 | Réservé | | Ne pas connecter
25 | Réservé | | Ne pas connecter
27 | GND | | Masse
29 | Réservé | | Ne pas connecter
31 | Réservé | | Ne pas connecter
33 | GND | | Masse
35 | Réservé | | Ne pas connecter
37 | Réservé | | Ne pas connecter
39 | GND | | Masse
41 | SATA_B_P | O | Signal différentiel + de 100 Ohm, sort du SSD
43 | SATA_B_N | O | Signal différentiel - de 100 Ohm, sort du SSD
45 | GND
47 | SATA_A_N | I | Signal différentiel - de 100 Ohm, entrant
49 | SATA_A_P | I | Signal différentiel + de 100 Ohm, entrant
51 | GND | | Masse
53 | Réservé | | Ne pas connecter
55 | Réservé | | Ne pas connecter
57 | GND | | Masse
59 | Clé | | Ne pas connecter
61 | Clé | | Ne pas connecter
63 | Clé | | Ne pas connecter
65 | Clé | | Ne pas connecter
67 | Réservé | | Ne pas connecter
69 | SATA_CONFIG1 | I | Connecter à la masse
71 | GND | | Masse
73 | GND | | Masse
75 | SATA_CONFIG2 | I | Connecter à la masse

Projet | Identifiant document | Niveau de sensibilité | Révision
Bourgeon | 001-001-HRS-FR-V1.0 | Ouvert | RA
08/2022 | Page 40 sur 78

Côté 2

Broche | Type | Niveau de tension Haut | Description
N° | Nom
2 | +3.3V_SATA | I | | Alimentation +3.3V total 2A
4 | +3.3V_SATA | I | | Alimentation +3.3V total 2A
6 | Réservé | | | Ne pas connecter
8 | Réservé | | | Ne pas connecter
10 | SATA_DAS/DSS# | O | +3.3V | Signal d’activité du SSD

Détrompeur

20 | Réservé | | | Ne pas connecter
22 | Réservé | | | Ne pas connecter
24 | Réservé | | | Ne pas connecter
26 | Réservé | | | Ne pas connecter
28 | Réservé | | | Ne pas connecter
30 | Réservé | | | Ne pas connecter
32 | Réservé | | | Ne pas connecter
34 | Réservé | | | Ne pas connecter
36 | Réservé | | | Ne pas connecter
38 | SATA_DEVSLP | I | +3.3V | Veille du SSD
40 | Réservé | | | Ne pas connecter
42 | Réservé | | | Ne pas connecter
44 | Réservé | | | Ne pas connecter
46 | Réservé | | | Ne pas connecter
48 | Réservé | | | Ne pas connecter
50 | Réservé | | | Ne pas connecter
52 | Réservé | | | Ne pas connecter
54 | Réservé | | | Ne pas connecter
56 | SATA_I2C_CLK | I | +3.3V | Horloge, I2C
58 | SATA_I2C_SDA | I/O | +3.3V | Données, I2C
60 | Clé | | | Ne pas connecter

Projet | Identifiant document | Niveau de sensibilité | Révision
Bourgeon | 001-001-HRS-FR-V1.0 | Ouvert | RA
08/2022 | Page 41 sur 78
62 | Clé | | Ne pas connecter
64 | Clé | | Ne pas connecter
66 | Clé | | Ne pas connecter
68 | Réservé | | Ne pas connecter
70 | +3.3V_SATA | I | Alimentation +3.3V total 2A
72 | +3.3V_SATA | I | Alimentation +3.3V total 2A
74 | +3.3V_SATA | I | Alimentation +3.3V total 2A

3.2.5.9 Carte SD

La mémoire carte SD peut servir à contenir le bootloader ou juste des données, selon utilisation.

Carte_IMX6_HRS_ [44]

Caractéristiques carte SD

- La carte SD doit être interfacée avec l’IMX6
- Le connecteur de la carte SD doit être au format micro SD

Inspection, niveau 1

Fin de l’exigence

Carte_IMX6_HRS_ [45]

Fonctions carte SD

- L’IMX6 doit pouvoir booter depuis la carte SD
- L’insertion d’une carte doit pouvoir être détectée par l’IMX6

Test, niveau 2

Fin de l’exigence

Projet | Identifiant document | Niveau de sensibilité | Révision
Bourgeon | 001-001-HRS-FR-V1.0 | Ouvert | RA
08/2022 | Page 42 sur 78
Broche | Type | Niveau de tension Haut | Description
N° | Nom
1 | SD_DATA2 | I/O | +3.3V ±0.1V | Signal de données 2
2 | SD_CD/DATA3 | I/O | | Détection de présence de carte / Signal de données 3
3 | SD_CMD | I/O | | Signal de commande
4 | +3.3V_SD | I | | Alimentation
5 | SD_CLK | I | | Signal d’horloge
6 | GND | | | Masse
7 | SD_DATA0 | I/O | +3.3V | Signal de données 0
8 | SD_DATA1 | I/O | | Signal de données 1
9 | SD_SWITCH | O | | Interrupteur de détection

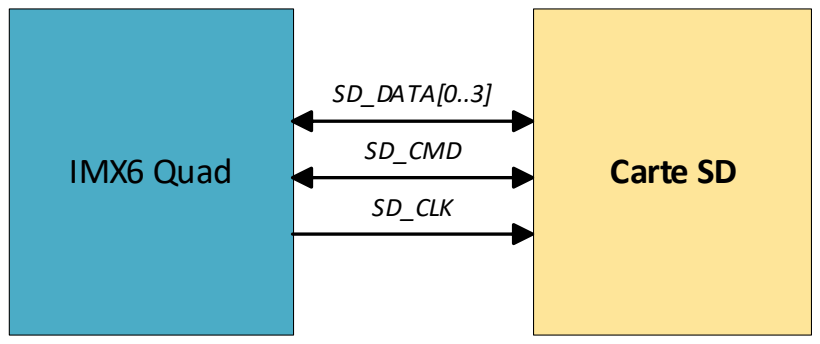
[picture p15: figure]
SD_DATA[0..3]; SD_CMD; SD_CLK

Projet | Identifiant document | Niveau de sensibilité | Révision
Bourgeon | 001-001-HRS-FR-V1.0 | Ouvert | RA
08/2022 | Page 43 sur 78 IMX6 Quad | Carte SD

Figure 17 : Interface Carte SD avec l'IMX6

3.2.5.10 GPIO

Carte_IMX6_HRS_ [46]

Caractéristiques GPIO

- La carte IMX6 doit comprendre un connecteur comprenant de broches d’alimentation, des GPIOs et différents bus :
- +3.3V ±0.1V 200mA
- +5V ±0.25V 200mA
- 26 GPIO dont 2 bus I2C, 2 bus SPI, deux PWM, un I2S et un UART (utilisation de bus en alternatif)
- Ce connecteur doit être des broches simples (header), avec un pas de 2.54mm, 20 broches sur deux rangées
- Le bus I2C doit être utilisé en mode standard (100kHz)
- Le bus UART doit avoir un baud rate configurable de 9600 à 1 000 000

Inspection, niveau 1

Fin de l’exigence

Carte_IMX6_HRS_ [47]

Protections GPIO

- L’alimentation des GPIO doit être protégée contre les tensions d’alimentation inverse, jusqu’à 12V
- L’alimentation des GPIO doit pouvoir supporter un court-circuit franc externe de manière continue, sans perturber le reste de l’article

Projet | Identifiant document | Niveau de sensibilité | Révision
Bourgeon | 001-001-HRS-FR-V1.0 | Ouvert | RA
08/2022 | Page 44 sur 78

Démonstration, niveau 1

Fin de l’exigence

UART, I2C, PWM,
GPIO...
IMX6 Quad | GPIO

Figure 18 : Interface GPIO avec l'IMX6

Broche | ALT | Type | Niveau de tension Haut | Description
N° | Nom
1 | +3.3V_GPIO | | I | | Alimentation +3.3V ±0.1V 200mA total
2 | +5V_GPIO | | I | | Alimentation +5V ±0.25V 200mA total
3 | GPIO_1 | SDA_1 | I/O | +3.3V | GPIO, Signal de données de l’I2C 1
4 | +5V_GPIO | | I | | Alimentation +5V ±0.25V 200mA total
5 | GPIO_2 | SCL_1 | I/O | +3.3V | GPIO, Signal d’horloge de l’I2C 1
6 | GND | | | | Masse
7 | GPIO_3 | I2S_RxD | I/O | +3.3V | GPIO, I2S
8 | GPIO_4 | UART_TxD | I/O | +3.3V | GPIO, signal de transmission du UART
9 | GND | | | | Masse
10 | GPIO_5 | UART_RxD | I/O | +3.3V | GPIO, signal d’émission du UART
11 | GPIO_6 | I2S_TxD | I/O | +3.3V | GPIO, I2S
12 | GPIO_7 | PWM_0 | I/O | +3.3V | GPIO, signal PWM 0
13 | GPIO_8 | I2S_TxC | I/O | +3.3V | GPIO, I2S
14 | GND | | | | Masse
15 | GPIO_9 | I2S_TxFS | I/O | +3.3V | GPIO, I2S
16 | GPIO_10 | I2S_CLK | I/O | +3.3V | GPIO, I2S
17 | +3.3V_GPIO | | I | | Alimentation +3.3V ±0.1V 200mA total

Projet | Identifiant document | Niveau de sensibilité | Révision
Bourgeon | 001-001-HRS-FR-V1.0 | Ouvert | RA
08/2022 | Page 45 sur 78
18 | GPIO_11 | | I/O | +3.3V | GPIO
19 | GPIO_12 | SPI0_MOSI | I/O | +3.3V | GPIO, bus SPI signal de maître à esclave
20 | GND | | | | Masse
21 | GPIO_13 | SPI0_MISO | I/O | +3.3V | GPIO, bus SPI signal d’esclave à maître
22 | GPIO_14 | | I/O | +3.3V
23 | GPIO_15 | SPI0_CLK | I/O | +3.3V | GPIO, bus SPI signal d’horloge
24 | GPIO_16 | SPI0_CS0 | I/O | +3.3V | GPIO, bus SPI signal de sélection 0
25 | GND | | | | Masse
26 | GPIO_17 | SPI0_CS1 | I/O | +3.3V | GPIO, bus SPI signal de sélection 1
27 | GPIO_18 | SDA_0 | I/O | +3.3V | GPIO, Signal de données de l’I2C 0
28 | GPIO_19 | SCL_0 | I/O | +3.3V | GPIO, Signal d’horloge de l’I2C 1
29 | GPIO_20 | | I/O | +3.3V | GPIO
30 | GND | | | | Masse
31 | GPIO_21 | | I/O | +3.3V | GPIO
32 | GPIO_22 | PWM_1 | I/O | +3.3V | GPIO, signal PWM 1
33 | GPIO_23 | | I/O | +3.3V | GPIO
34 | GND | | | | Masse
35 | GPIO_24 | | I/O | +3.3V | GPIO
36 | GPIO_25 | | I/O | +3.3V | GPIO
37 | GPIO_26 | | I/O | +3.3V | GPIO
38 | GPIO_27 | | I/O | +3.3V | GPIO
39 | GND | | | | Masse
40 | GPIO_28 | | I/O | +3.3V | GPIO

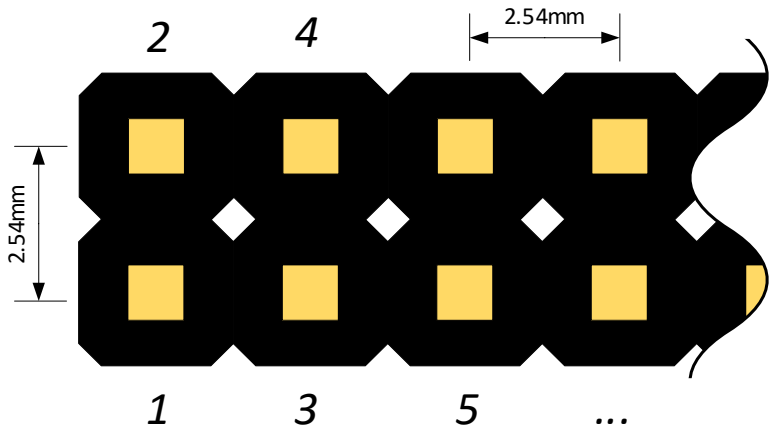
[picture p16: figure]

Projet | Identifiant document | Niveau de sensibilité | Révision
Bourgeon | 001-001-HRS-FR-V1.0 | Ouvert | RA
08/2022 | Page 46 sur 78

08/2022 | Page 47 sur 78

3.2.5.11 HDMI

Carte_IMX6_HRS_ [48]

Caractéristiques HDMI

- La carte doit comporter un connecteur HDMI interfacé avec l’IMX6
- L’interface HMDI doit être conforme au standard [S8]

Inspection, niveau 1

Fin de l’exigence

Carte_IMX6_HRS_ [49]

Protection HDMI

- Le l’interface HDMI doit supporter des décharges ESD conformément à la norme [N1] niveau 3
- Le +5V de l’interface HDMI doit supporter les courts circuits externes : limitation du courant à 60mA
- L’interface HDMI doit être protégée contre l’alimentation inverse sur les broches SCL, SDA, DETECT, CEC

Test, niveau 1

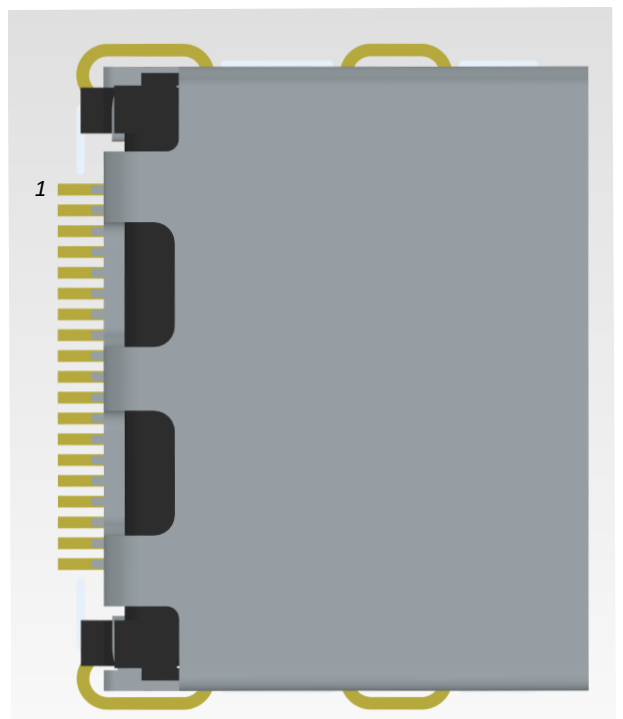
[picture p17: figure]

Projet | Identifiant document | Niveau de sensibilité | Révision
Bourgeon | 001-001-HRS-FR-V1.0 | Ouvert | RA
08/2022 | Page 48 sur 78

Figure 19 : Interface du HDMI avec l'IMX6

Broche | Type | Niveau de tension Haut | Description
N° | Nom
1 | HDMI_D2_P | I/O | +3.3V-400mV à 600mV | Signal de données 2 positif, 100Ohm ±10% différentiel
2 | GND | | | Masse
3 | HDMI_D2_N | I/O | +3.3V-400mV à 600mV | Signal de données 2 négatif, 100Ohm ±10% différentiel
4 | HDMI_D1_P | I/O | +3.3V-400mV à 600mV | Signal de données 1 positif, 100Ohm ±10% différentiel
5 | GND | | | Masse
6 | HDMI_D1_N | I/O | +3.3V-400mV à 600mV | Signal de données 1 négatif, 100Ohm ±10% différentiel
7 | HDMI_D0_P | I/O | +3.3V-400mV à 600mV | Signal de données 0 positif, 100Ohm ±10% différentiel

Projet | Identifiant document | Niveau de sensibilité | Révision
Bourgeon | 001-001-HRS-FR-V1.0 | Ouvert | RA
08/2022 | Page 49 sur 78
8 | GND | | | Masse
9 | HDMI_D0_N | I/O | +3.3V-400mV à 600mV | Signal de données 0 négatif, 100Ohm ±10% différentiel
10 | HDMI_CLK_P | I/O | +3.3V-400mV à 600mV | Signal d’horloge positif, 100Ohm ±10% différentiel
11 | GND | | | Masse
12 | HDMI_CLK_N | I/O | +3.3V-400mV à 600mV | Signal d’horloge négatif, 100Ohm ±10% différentiel
13 | HDMI_CEC | I/O | 2.4 à 5.4V | Signal CEC
14 | HDMI_HEC | | | Ne pas connecter
15 | HDMI_SCL | I | 2.4 à 5.4V | Horloge, I2C
16 | HDMI_SDA | I/O | 2.4 à 5.4V | Données, I2C
17 | GND | | | Masse
18 | +5V_HDMI | I | +5V ±5% | Alimentation HMDI, 50mA
19 | HDMI_DETECT | O | 2.4 à 5.4V | Détection du câble HDMI

Projet | Identifiant document | Niveau de sensibilité | Révision
Bourgeon | 001-001-HRS-FR-V1.0 | Ouvert | RA
08/2022 | Page 50 sur 78

3.2.5.12 Interface Utilisateur (LEDs, Boutons)

Carte_IMX6_HRS_ [50]

Contenu interface utilisateur

- L’interface utilisateur doit comprendre 5 LEDs et 3 boutons poussoir situées sur le dessus de la carte, numérotées et regroupés dans une même zone
- Les LEDs et boutons doivent être reliés à des broches GPIO de l’IMX6
- Un bouton Power, pour changer le mode de l’IMX6 (allumé éteint)

Inspection, niveau 1

Fin de l’exigence

Carte_IMX6_HRS_ [51]

Interface utilisateur, bouton POWER

- Le bouton Power doit suivre le tableau suivant :
Mode de transition | Appui bouton POWER
Eteint à premier allumage | Court
Allumé à Eteindre | Court
Allumé à éteindre, forcé | Long, 5 secondes

Démonstration, niveau 1

Fin de l’exigence

Projet | Identifiant document | Niveau de sensibilité | Révision
Bourgeon | 001-001-HRS-FR-V1.0 | Ouvert | RA
08/2022 | Page 51 sur 78

BP[0..2]

LED[0...4]

RESET/Power

Bouton Reset/
Power

LEDs x5

Boutons x3

IMX6 Quad

Figure 20 : Interface utilisateur
3.2.5.13 Connecteur d’extension

Carte_IMX6_HRS_ [52]

Connecteur d’extension, mécanique

- Le connecteur doit être carte à carte, de type M.2 NGFF
- La clé détrompeuse doit être de type E

Inspection, niveau 1

Fin de l’exigence

Carte_IMX6_HRS_ [53]

Dimensions carte fille connecteur d’extension

- La carte fille doit avoir les dimensions d’une carte M.2 de format 2280
- La carte connectée doit avoir un espace libre de 2mm en dessous et 10mm au-dessus

Inspection, niveau 1

Fin de l’exigence

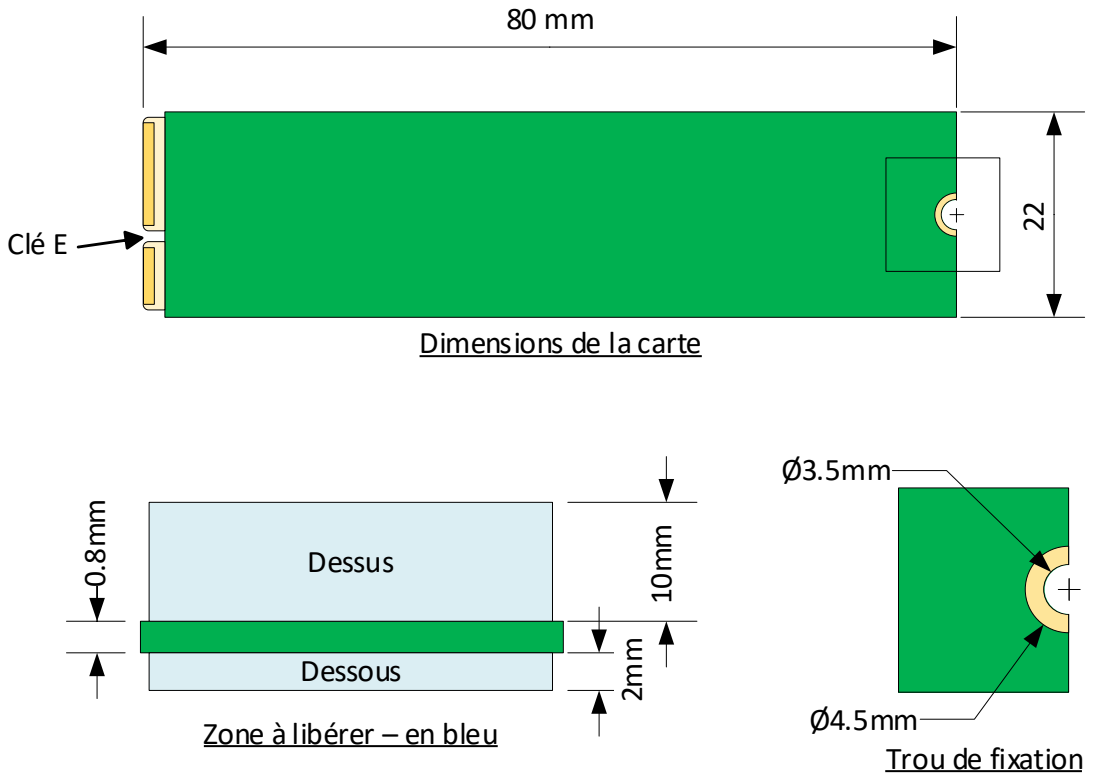
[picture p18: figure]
Clé E; Zone à libérer – en bleu; Dessus; Trou de fixation; Dessous; Dimensions de la carte

Projet | Identifiant document | Niveau de sensibilité | Révision
Bourgeon | 001-001-HRS-FR-V1.0 | Ouvert | RA
08/2022 | Page 52 sur 78

Projet | Identifiant document | Niveau de sensibilité | Révision
Bourgeon | 001-001-HRS-FR-V1.0 | Ouvert | RA
08/2022 | Page 53 sur 78

Carte_IMX6_HRS_ [54]

Contenu du connecteur d’extension

- Cette interface doit comprendre les bus :
- SPI
- I2C
- UART, avec un baud rate de 112500
- CAN
- USB
- SD avec 8 signaux de données
- Cette interface doit comprendre diverses broches d’alimentation :
- L’alimentation +5V de la carte, pouvant être utilisée dans les deux sens, 4A vers la carte mère, 750mA vers la carte fille
- Du +3.3V 500mA issu des régulateurs de la carte, vers la carte fille
- Cette interface doit comprendre 10 GPIO :
- Pouvant être utilisé comme I/O logiques
- Avec des résistances de tirage vers le haut/bas configurables par logiciel
- Une broche connectée au système on/off de l’IMX6

Inspection, niveau 1

Fin de l’exigence

Carte_IMX6_HRS_ [55]

Performance connecteur d’extension

- L’I2C doit être standard, soit avec une vitesse de 100kHz, et permettre une capacité du bus allant jusqu’à 500pF
- Le SPI doit avoir une fréquence allant jusqu’à 10MHz, en full duplex
- Le bus SD doit permettre un débit de 100Mo/s lecture et écriture

Test, niveau 1

Fin de l’exigence

Projet | Identifiant document | Niveau de sensibilité | Révision
Bourgeon | 001-001-HRS-FR-V1.0 | Ouvert | RA
08/2022 | Page 54 sur 78

Côté 1

Broche | Type | Niveau de tension Haut | Description
N° | Nom
1 | GND | | | Masse
3 | +5V | I/O | +5V ±0.25V | Alimentation régulée +5V 4A max (total) en sortie, 750mA en entrée 5
| +5V
7 | GND | | | Masse
9 | +5V | I/O | +5V ±0.25V | Alimentation régulée +5V 4A max (total) en sortie, 750mA en entrée 11
| +5V
13 | GND | | | Masse
15 | +5V | I/O | +5V ±0.25V | Alimentation régulée +5V 4A max (total) en sortie, 750mA en entrée 17
| +5V
19 | GND | | | Masse
21 | +5V | I/O | +5V ±0.25V | Alimentation régulée +5V 4A max (total) en sortie, 750mA en entrée 23
| +5V

Détrompeur

33 | GND | | | Masse
35 | +5V | I/O | +5V ±0.25V | Alimentation régulée +5V 4A max (total) en sortie, 750mA en entrée
37 | GND | | | Masse
39 | +3,3V_CdE | I | +3.3V ±0.1V | Alimentation régulée +3.3V 500mA
41 | +3,3V_CdE
43 | GND | | | Masse
45 | CdE_SPI_MOSI | I | +3.3V | SPI broche maître à esclave
47 | CdE_SPI_MISO | O | | SPI broche esclave à maître
49 | GND | | | Masse
51 | CdE_SPI_CLK | I | +3.3V | Horloge du SPI
53 | CdE_SPI_CS0 | I | | SPI broche Chip Select 0
55 | CdE_SPI_CS1 | I | | SPI broche Chip Select 1
57 | GND | | | Masse

Projet | Identifiant document | Niveau de sensibilité | Révision
Bourgeon | 001-001-HRS-FR-V1.0 | Ouvert | RA
08/2022 | Page 55 sur 78
59 | CdE_GPIO1 | I/O | +3.3V | Broches GPIO
61 | CdE_GPIO2
63 | CdE_GPIO3
65 | CdE_GPIO4
67 | CdE_GPIO5
69 | CdE_GPIO6
71 | CdE_GPIO7
73 | CdE_GPIO8
75 | CdE_GPIO9

Côté 2

Broche | Type | Niveau de tension Haut | Description
N° | Nom
2 | CdE_SD_DATA0 | I/O | +3.3V | Signal de données [0..3] Impédance de 50Ohm
4 | CdE_ SD_DATA1
6 | CdE_ SD_DATA2
8 | CdE_ SD_DATA3
10 | GND | | | Masse
12 | CdE_ SD_DATA4 | I/O | +3.3V | Signal de données [4..7] Impédance de 50Ohm
14 | CdE_ SD_DATA5
16 | CdE_ SD_DATA6
18 | CdE_ SD_DATA7
20 | CdE_ SD_CLK | I | | Horloge bus SD Impédance de 50Ohm
22 | CdE_ SD_CMD | I/O | | Commandes bus SD Impédance de 50Ohm

Détrompeur

32 | CdE_ SD_RESET | I/O | +3.3V | RESET du périphérique SD
34 | GND | | | Masse

Projet | Identifiant document | Niveau de sensibilité | Révision
Bourgeon | 001-001-HRS-FR-V1.0 | Ouvert | RA
08/2022 | Page 56 sur 78
36 | GND | | | Masse
38 | CdE_ UART_RxD | I | +3.3V | Réception données UART
40 | CdE_ UART_TxD | O | | Emission données UART
42 | GND | | | Masse
44 | GND | | | Masse
46 | CdE_ CAN_P | I/O | +3.3V | Bus CAN
48 | CdE_ CAN_N | I/O | | Bus CAN
50 | GND | | | Masse
52 | GND | | | Masse
54 | CdE_ I2C_SDA | I/O | +3.3V | Données bus I2C
56 | CdE_ I2C_SCL | I | | Horloge bus I2C
58 | GND | | | Masse
60 | GND | | | Masse
62 | CdE_ USB_D- | I/O | | Bus USB Impédance de 50Ohm
64 | CdE_ USB_D+ | I/O | | Bus USB Impédance de 50Ohm
66 | GND | | | Masse
68 | GND | | | Masse
70 | CdE_ OnOFF_IMX6 | O | +3.3V | Broche reliée au bouton On OFF de l’IMX6
72 | GND | | | Masse
74 | CdE_ GPIO10 | I/O | +3.3V | Broche GPIO

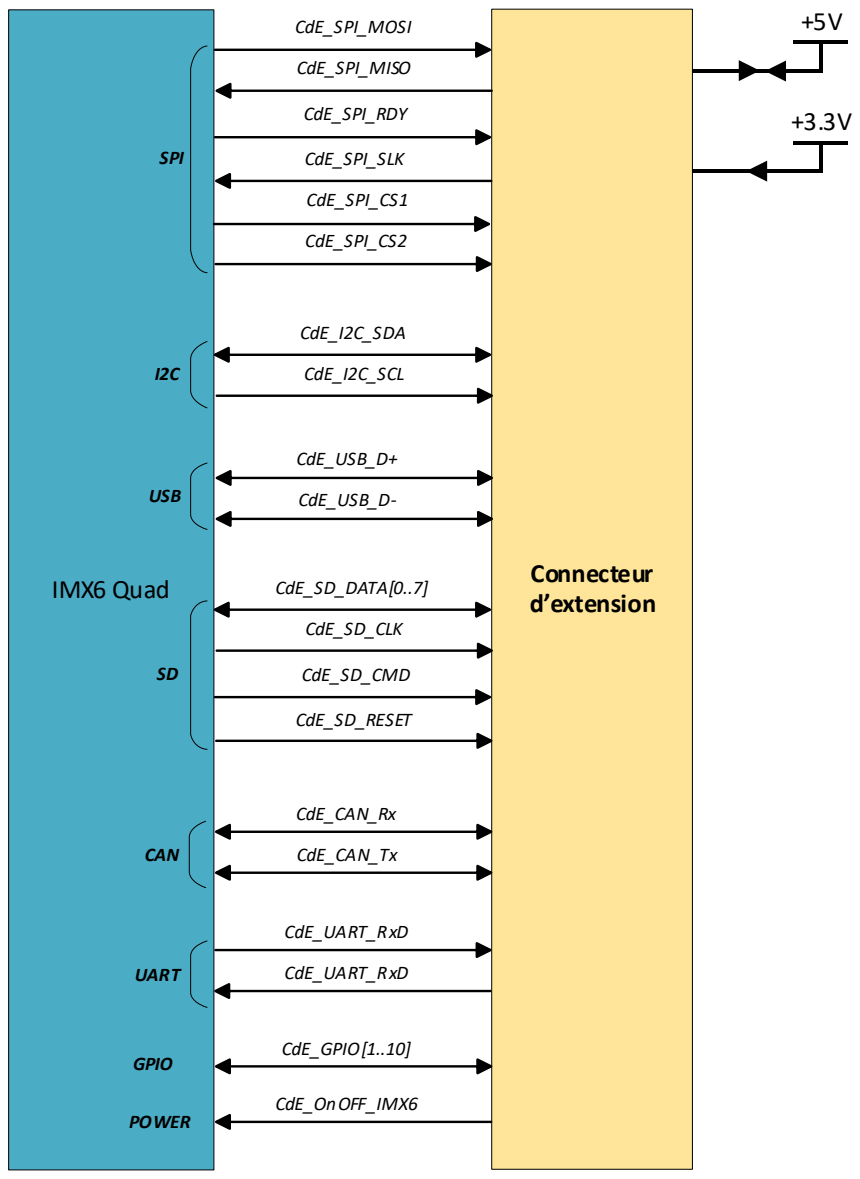
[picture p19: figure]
IMX6 Quad; Connecteur; d extension; CdE_SPI_MOSI; CdE_SPI_MISO; CdE_SPI_RDY; CdE_SPI_SLK; CdE_SPI_CS1; CdE_SPI_CS2; CdE_I2C_SDA; CdE_I2C_SCL; CdE_USB_D+; CdE_USB_D-; CdE_SD_DATA[0..7]; CdE_SD_CLK; CdE_SD_CMD; CdE_SD_RESET; CdE_CAN_Rx; CdE_CAN_Tx; CdE_UART_RxD; CdE_GPIO[1..10]; CdE_OnOFF_IMX6; SPI; USB; CAN; UART; GPIO; POWER

Projet | Identifiant document | Niveau de sensibilité | Révision
Bourgeon | 001-001-HRS-FR-V1.0 | Ouvert | RA
08/2022 | Page 57 sur 78

Figure 21 : Interface du connecteur d'extension et de l'IMX6

Projet | Identifiant document | Niveau de sensibilité | Révision
Bourgeon | 001-001-HRS-FR-V1.0 | Ouvert | RA
08/2022 | Page 58 sur 78

# 4 EXIGENCES NON FONCTIONNELLES

## 4.1 SURETE DE FONCTIONNEMENT

4.1.1 FIABILITE

Carte_IMX6_HRS_ [56]

MTBF

- La MTBF de la carte doit être de 100 000h minimum, à 25°C avec une humidité atmosphérique de 50%

Test, niveau 1

Fin de l’exigence

4.1.2 DISPONIBILITE

Sans objet

4.1.3 MAINTENABILITE / TESTABILITE

Carte_IMX6_HRS_ [57]

Points de test

- L’article doit comporter des points de test sur :
- Les différents bus I2C, SPI et UART utilisés
- La tension d’entrée (non régulée)
- Les différentes tensions régulées
- La masse, en 3 endroits différents éloignés
- L’audio en entrée sortie, côté analogique
- Les points de test doivent être sur le dessus de la carte, avec un diamètre minimum de 1mm

Inspection, niveau 1

Fin de l’exigence

Projet | Identifiant document | Niveau de sensibilité | Révision
Bourgeon | 001-001-HRS-FR-V1.0 | Ouvert | RA
08/2022 | Page 59 sur 78

4.1.4 SECURITE DES PERSONNES ET DU MATERIEL

Sans objet

## 4.2 EXIGENCES DE CONCEPTION ET DE REALISATION

4.2.1 REUSABILITE

Sans objet

4.2.2 IP IDENTIFICATION

Carte_IMX6_HRS_ [58]

Sérigraphie connecteur d’alimentation

- Un marquage spécifiant le courant demandé par la carte doit être inscrit sur la carte

Inspection, niveau 1

Fin de l’exigence

Carte_IMX6_HRS_ [59]

Sérigraphie JTAG

- Une indication du type d’interface doit être présent à côté du connecteur JTAG (inscription JTAG)

Inspection, niveau 1

Fin de l’exigence

Carte_IMX6_HRS_ [60]

Sérigraphie GPIO

Projet | Identifiant document | Niveau de sensibilité | Révision
Bourgeon | 001-001-HRS-FR-V1.0 | Ouvert | RA
08/2022 | Page 60 sur 78
- Il doit être sérigraphié près du connecteur GPIO :
- Le niveau de tension accepté (3.3V)
- La broche 1 du connecteur

Inspection, niveau 1

Fin de l’exigence

Carte_IMX6_HRS_ [61]

Sérigraphie m.2 SATA

- Une indication du type d’interface doit être présent à côté du connecteur SATA

Inspection, niveau 1

Fin de l’exigence

Carte_IMX6_HRS_ [62]

Sérigraphie connecteur d’extension

- Une indication sur la sérigraphie doit être présente, indiquant que le brochage du connecteur n’est pas standard

Inspection, niveau 1

Fin de l’exigence

Projet | Identifiant document | Niveau de sensibilité | Révision
Bourgeon | 001-001-HRS-FR-V1.0 | Ouvert | RA
08/2022 | Page 61 sur 78

Carte_IMX6_HRS_ [63]

Sérigraphie à remplir manuellement

- Un marquage doit permettre la notation manuelle de l’adresse IP de la carte
- Un marquage doit permettre la notation manuelle du numéro de la carte

Inspection, niveau 1

Fin de l’exigence

Figure 22 : Exemple de sérigraphie à remplir manuellement

4.2.3 TRANSPORTABILITE

Carte_IMX6_HRS_ [64]

Emballage transport

- La carte doit être transportée dans un sachet antistatique métallisé (blindage intérieur) scellé.
- Le sachet antistatique doit être conforme à la norme [N2]

Inspection, niveau 1

Fin de l’exigence

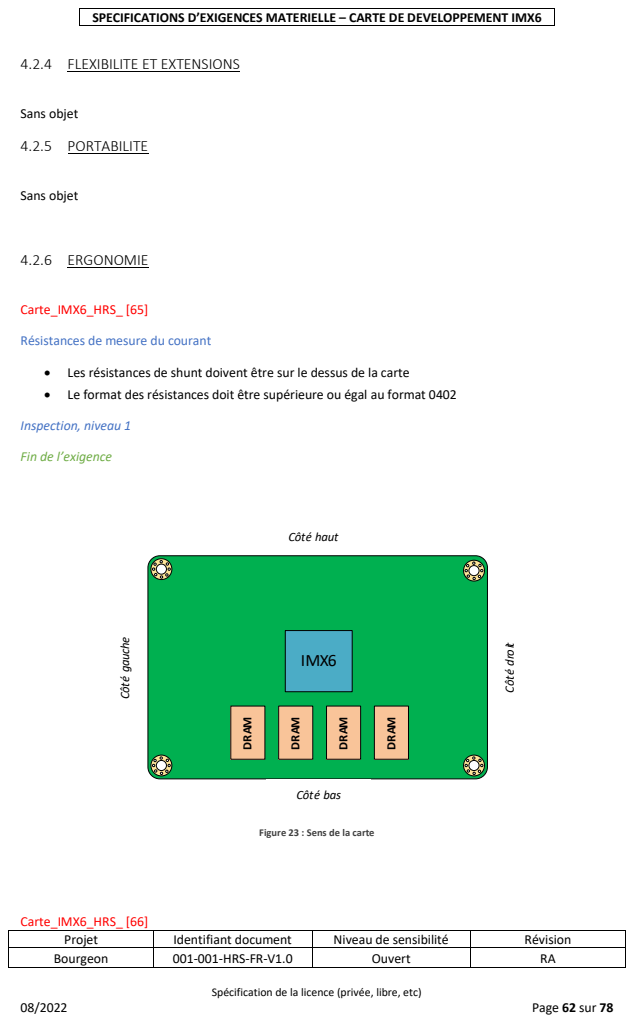
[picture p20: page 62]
Page 62 sur 78; Sans objet; 4.2.5 PORTABILITE; 4.2.6 ERGONOMIE; Carte_IMX6_HRS_ [65]; Inspection, niveau 1; Côté gauche; Côté haut; Côté bas; IMX6; DRAM; Carte_IMX6_HRS_ [66]

4.2.4 FLEXIBILITE ET EXTENSIONS

Résistances de mesure du courant

• Les résistances de shunt doivent être sur le dessus de la carte
• Le format des résistances doit être supérieure ou égal au format 0402

Fin de l’exigence

Côté dro it

Figure 23 : Sens de la carte

Projet | Identifiant document | Niveau de sensibilité | Révision
Bourgeon | 001-001-HRS-FR-V1.0 | Ouvert | RA

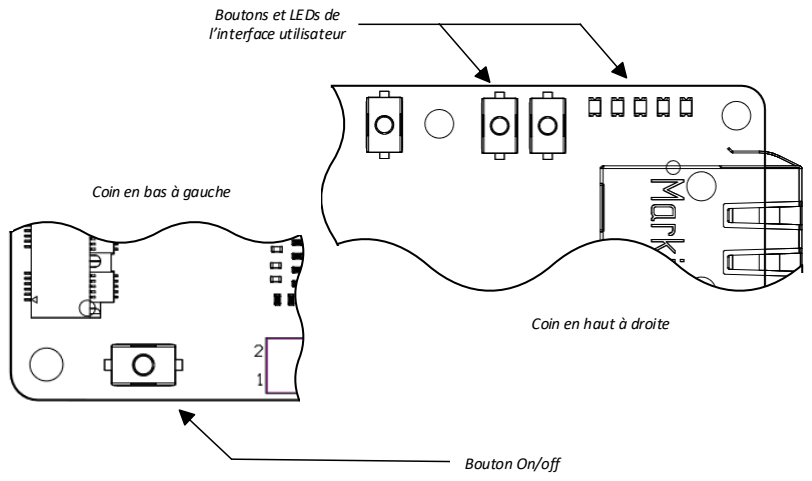
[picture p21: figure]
Boutons et LEDs de l interface utilisateur; Bouton On/off; Coin en bas à gauche; Coin en haut à droite

Projet | Identifiant document | Niveau de sensibilité | Révision
Bourgeon | 001-001-HRS-FR-V1.0 | Ouvert | RA
08/2022 | Page 63 sur 78

Disposition de l’interface utilisateur

- Les boutons et les de l’interface utilisateur doivent être situés dans le coin en haut à droite de la carte
- Le bouton on/off de la carte doit être dans le coin en bas à gauche

Inspection, niveau 1

Fin de l’exigence

Figure 24 ; Disposition des constituants de l'interface utilisateur

Carte_IMX6_HRS_ [67]

Disposition des connecteurs

- Le côté droit de la carte doit comporter les ports USB HOST et OTG ainsi que le port RJ45, situés sur le dessus de la carte
- Le côté gauche de la carte doit comporter le port HDMI ainsi que le port d’alimentation situés sur le dessus de la carte
- Le côté haut de la carte doit comporter le slot de la carte SD
- Le côté bas de la carte doit comporter le connecteur GPIO ainsi que le l’audio jack
- Le connecteur JTAG doit être situé sur le haut de la carte

La disposition des autres connecteurs est laissée libre.

Inspection, niveau 1

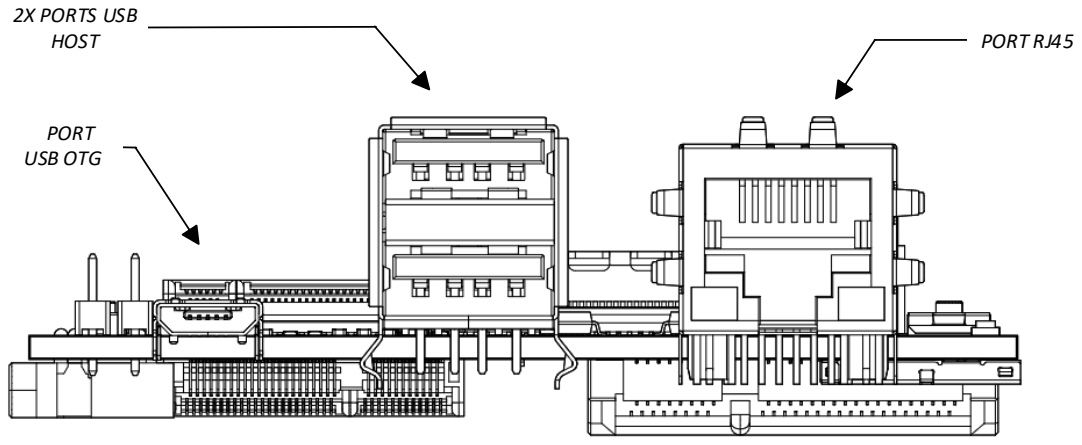
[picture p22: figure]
PORT RJ45; 2X PORTS USB HOST; PORT USB OTG

Projet | Identifiant document | Niveau de sensibilité | Révision
Bourgeon | 001-001-HRS-FR-V1.0 | Ouvert | RA
08/2022 | Page 64 sur 78

Fin de l’exigence

Figure 25 : Disposition des connecteurs, côté droit de l’article

Figure 26 : Disposition des connecteurs, côté gauche de l'article

Carte_IMX6_HRS_ [68]

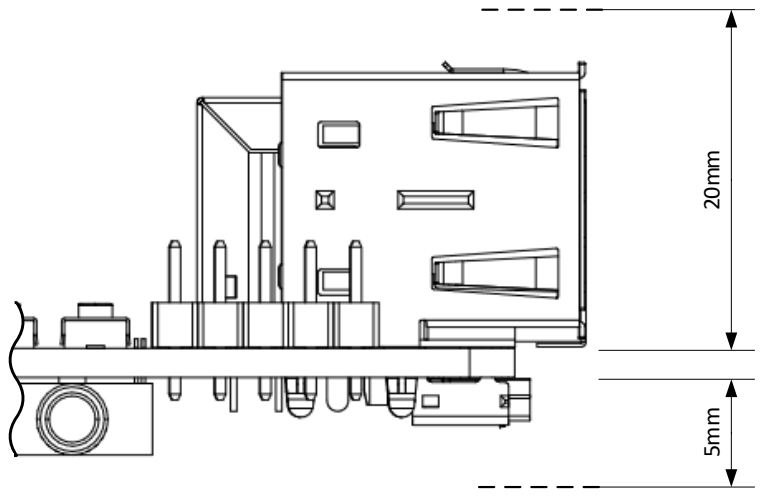
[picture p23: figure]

Projet | Identifiant document | Niveau de sensibilité | Révision
Bourgeon | 001-001-HRS-FR-V1.0 | Ouvert | RA
08/2022 | Page 65 sur 78

Encombrement de la carte

- Aucun connecteur ou composant ne doit dépasser de plus de 5mm au dehors de la surface de la carte
- L’encombrement au-dessus de la carte doit être de 20mm maximum
- L’encombrement au-dessous de la carte doit être de 5mm maximum

Inspection, niveau 1

Fin de l’exigence

Figure 27 : Représentation de l'encombrement maximal en hauteur

4.2.7 COMPOSANTS MATERIAUX ET PROCEDES

4.2.7.1 Composants

Sans objet

4.2.7.2 Matériaux

Projet | Identifiant document | Niveau de sensibilité | Révision
Bourgeon | 001-001-HRS-FR-V1.0 | Ouvert | RA
08/2022 | Page 66 sur 78

Sans objet

4.2.7.3 Procédés

Carte_IMX6_HRS_ [69]

Classe du PCB

- La qualité du PCB doit être de classe 2 selon la norme [N3]

Inspection, niveau 0

Fin de l’exigence

Carte_IMX6_HRS_ [70]

Finition du PCB

- La finition du PCB doit être de l’ENIG

Inspection, niveau 0

Fin de l’exigence

Carte_IMX6_HRS_ [71]

Masque de soudure

- Le masque de soudure de la carte doit pouvoir supporter 5 brasures successives

Test, niveau 1

Fin de l’exigence

Carte_IMX6_HRS_ [72]

Acceptabilité de l’assemblage

- La qualité de l’assemblage doit être de classe 2 selon la norme [N8]

Inspection, niveau 1

Fin de l’exigence

Projet | Identifiant document | Niveau de sensibilité | Révision
Bourgeon | 001-001-HRS-FR-V1.0 | Ouvert | RA
08/2022 | Page 67 sur 78

4.2.8 MARQUAGE DES PRODUITS

Marquage | Description | Zone / visibilité | taille
CE | Identifie l’article comme étant certifié CE | Sur la sérigraphie, dessus ou dessous, en zone dégagée | 5 mm de haut minimum Les proportions doivent être conservées
RoHS | Respect de la norme RoHS [N4] | Sur la sérigraphie, dessus ou dessous, en zone dégagée | Doit être lisible à l’œil nu
Nom et Version | Identification de la carte par le nom et la version | Sur la sérigraphie du dessus | Doit être lisible à l’œil nu

4.2.9 NORMALISATION INDUSTRIELLE

Sans objet

4.2.10 INTERCHANGEABILITE

Sans objet

4.2.11 EXIGENCES RELATIVES A LA SECURITE – CONFIDENTIALITE ET PROTECTIONS

Sans objet

4.2.12 PROPRIETE ET CONTROLE DE L’EXPORTATION

Sans objet

4.2.13 EXIGENCES RELATIVES A LA LIVRAISON ET A LA PROCEDURE DE CHARGEMENT

Projet | Identifiant document | Niveau de sensibilité | Révision
Bourgeon | 001-001-HRS-FR-V1.0 | Ouvert | RA
08/2022 | Page 68 sur 78

Sans objet

4.2.14 UPGRADE – INTERCHANGEABILITE

Carte_IMX6_HRS_ [73]

Boitier mémoire flash

- La mémoire Flash doit être dans un boîtier facilement remplaçable à l’aide d’air chaud, avec des broches accessibles pour une vérification visuelle

Inspection, niveau 1

Fin de l’exigence

4.2.15 CARACTERISTIQUES DES ELEMENTS SECONDAIRES

Sans objet

# 5 CARACTERISTIQUES PHYSIQUES ET INTERFACES

## 5.1 CARACTERISTIQUES PHYSIQUES

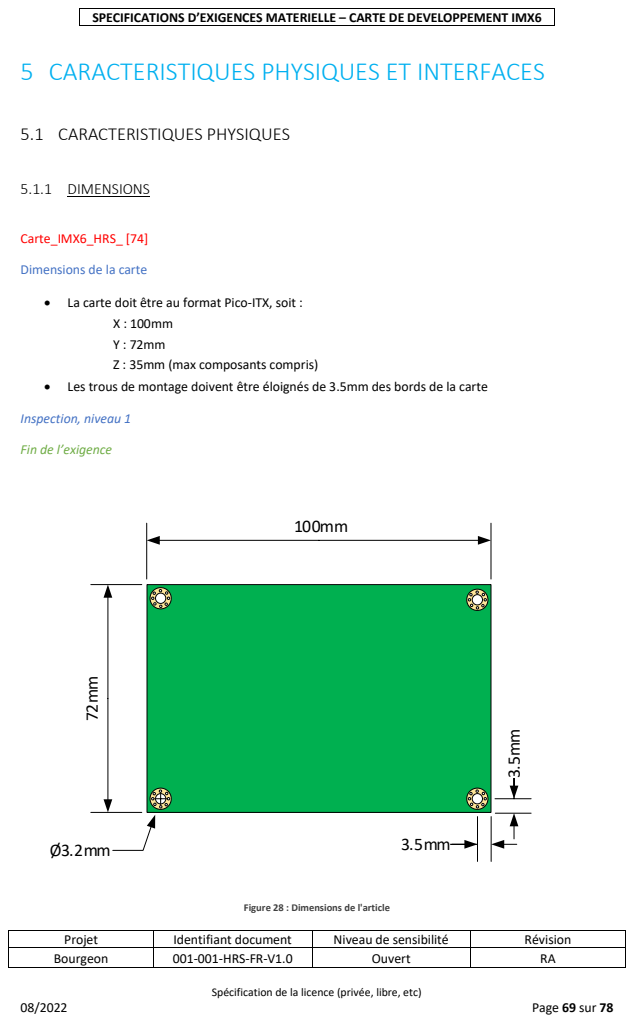
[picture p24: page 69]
Page 69 sur 78; 5.1.1 DIMENSIONS; Carte_IMX6_HRS_ [74]; Z : 35mm (max composants compris); Inspection, niveau 1

Dimensions de la carte

• La carte doit être au format Pico-ITX, soit :

• Les trous de montage doivent être éloignés de 3.5mm des bords de la carte

Fin de l’exigence

Figure 28 : Dimensions de l'article

Projet | Identifiant document | Niveau de sensibilité | Révision
Bourgeon | 001-001-HRS-FR-V1.0 | Ouvert | RA

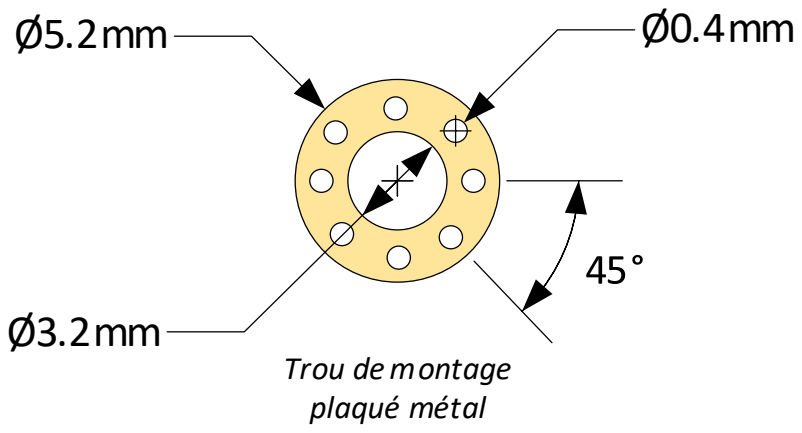
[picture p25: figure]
Trou de montage plaqué métal

Projet | Identifiant document | Niveau de sensibilité | Révision
Bourgeon | 001-001-HRS-FR-V1.0 | Ouvert | RA
08/2022 | Page 70 sur 78

Carte_IMX6_HRS_ [75]

Dimensions des trous de montage

- Les trous de montage doivent être constitués d’un trou métallisé de diamètre 3.2mm, entourés d’un anneau métallique totalisant le diamètre total à 5.2mm
- L’anneau métallisé possède 8 trous métallisés de 0.4mm de diamètre chacun, répartis à distance égale

Inspection, niveau 1

Fin de l’exigence

Carte_IMX6_HRS_ [76]

Trous de montage, électrique

- Les trous de montage doivent être reliés à la masse de l’article

Inspection, niveau 1

Fin de l’exigence

Figure 29 : Dimensions des trous de montage

Projet | Identifiant document | Niveau de sensibilité | Révision
Bourgeon | 001-001-HRS-FR-V1.0 | Ouvert | RA
08/2022 | Page 71 sur 78

5.1.2 MASSE

Carte_IMX6_HRS_ [77]

Masse de la carte IMX6

- La masse de la carte ne doit pas dépasser 500g

Inspection, niveau 1

Fin de l’exigence

## 5.2 INTERFACES

5.2.1 INTERFACES PHYSIQUES

Sans objet

5.2.2 INTERFACES ELECTRIQUES

Sans objet

5.2.3 INTERFACES MECANIQUES

Sans objet

5.2.4 INTERFACES LOGIQUES

Sans objet

Projet | Identifiant document | Niveau de sensibilité | Révision
Bourgeon | 001-001-HRS-FR-V1.0 | Ouvert | RA
08/2022 | Page 72 sur 78

# 6 ENVIRONNEMENT SPECIFIQUE MODULE

## 6.1 ENVIRONNEMENT CLIMATIQUE

Carte_IMX6_HRS_ [78]

Température carte IMX6

- La carte IMX6 doit fonctionner dans une plage de température de 0 à 85°C

Test, niveau 1

Fin de l’exigence

Carte_IMX6_HRS_ [79]

Humidité carte IMX6

- La carte IMX6 doit fonctionner par une humidité atmosphérique allant de 10 à 70%

Test, niveau 1

Fin de l’exigence

Projet | Identifiant document | Niveau de sensibilité | Révision
Bourgeon | 001-001-HRS-FR-V1.0 | Ouvert | RA
08/2022 | Page 73 sur 78

## 6.2 ENVIRONNEMENT MECANIQUE

Carte_IMX6_HRS_ [80]

Vibration carte IMX6

- La carte IMX6 doit être conforme à la norme [N5] méthode 514.6 procédure 1

Test, niveau 1

Fin de l’exigence

Carte_IMX6_HRS_ [81]

Choc carte IMX6

- La carte IMX6 doit être conforme à la norme [N5] méthode 516.6 Procédure 6

Test, niveau 1

Fin de l’exigence

## 6.3 ENVIRONNEMENT ELECTROMAGNETIQUE

Projet | Identifiant document | Niveau de sensibilité | Révision
Bourgeon | 001-001-HRS-FR-V1.0 | Ouvert | RA
08/2022 | Page 74 sur 78

Carte_IMX6_HRS_ [82]

Norme CEM carte IMX6

- La carte IMX6 doit être conforme à la norme [N6]

Test, niveau 1

Fin de l’exigence

Carte_IMX6_HRS_ [83]

Continuité de masse carte IMX6

- La carte IMX6 doit avoir des couches dédiées au plan de masse (2 minimum)
- Les plans de masse ne doivent pas être interrompus sur une surface de plus de 5mm² (hors trous de montage)

Inspection, niveau 0

Fin de l’exigence

## 6.4 ENVIRONNEMENT PHYSICO-CHIMIQUE

Sans objet

## 6.5 ENVIRONNEMENT BIOLOGIQUE

Sans objet

## 6.6 STOCKAGE

Projet | Identifiant document | Niveau de sensibilité | Révision
Bourgeon | 001-001-HRS-FR-V1.0 | Ouvert | RA
08/2022 | Page 75 sur 78

Carte_IMX6_HRS_ [84]

Stockage

- L’article doit pouvoir être stocké par une température de 0 à 85°C, et une humidité de 10 à 70%

Test, niveau 1

Fin de l’exigence

## 6.7 AUTRE ENVIRONNEMENT

Carte_IMX6_HRS_ [85]

Normes environnementales

- La carte IMX6 doit être conforme à la norme [N4]
- La carte doit avoir le marquage CE (soit respect de la norme [N4] et [N5] précédemment citées)

Analyse, niveau 1

Fin de l’exigence

Projet | Identifiant document | Niveau de sensibilité | Révision
Bourgeon | 001-001-HRS-FR-V1.0 | Ouvert | RA
08/2022 | Page 76 sur 78

# 7 VERIFICATION DES EXIGENCES

## 7.1 METHODE DE VERIFICATION

## 7.2 MATRICE DES EXIGENCES

Projet | Identifiant document | Niveau de sensibilité | Révision
Bourgeon | 001-001-HRS-FR-V1.0 | Ouvert | RA
08/2022 | Page 77 sur 78

# 8 SIGLES

Sigle | Signification

CE

RoHS

PCB

SATA

SD

UART

I2C

PCIe

CAN

JTAG

USB

SPI

Tx

ESD

HDMI

GPIO

Rx

USB OTG

RAM

DDR

EEPROM

IP

MQTT

IEEE

OS

IEC

IPC

CEM

JEDEC

NGFF

Projet | Identifiant document | Niveau de sensibilité | Révision
Bourgeon | 001-001-HRS-FR-V1.0 | Ouvert | RA
08/2022 | Page 78 sur 78

I2S

LoRA

SSD

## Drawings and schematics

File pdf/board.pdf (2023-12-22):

# Bourgeon IMX6 dev board

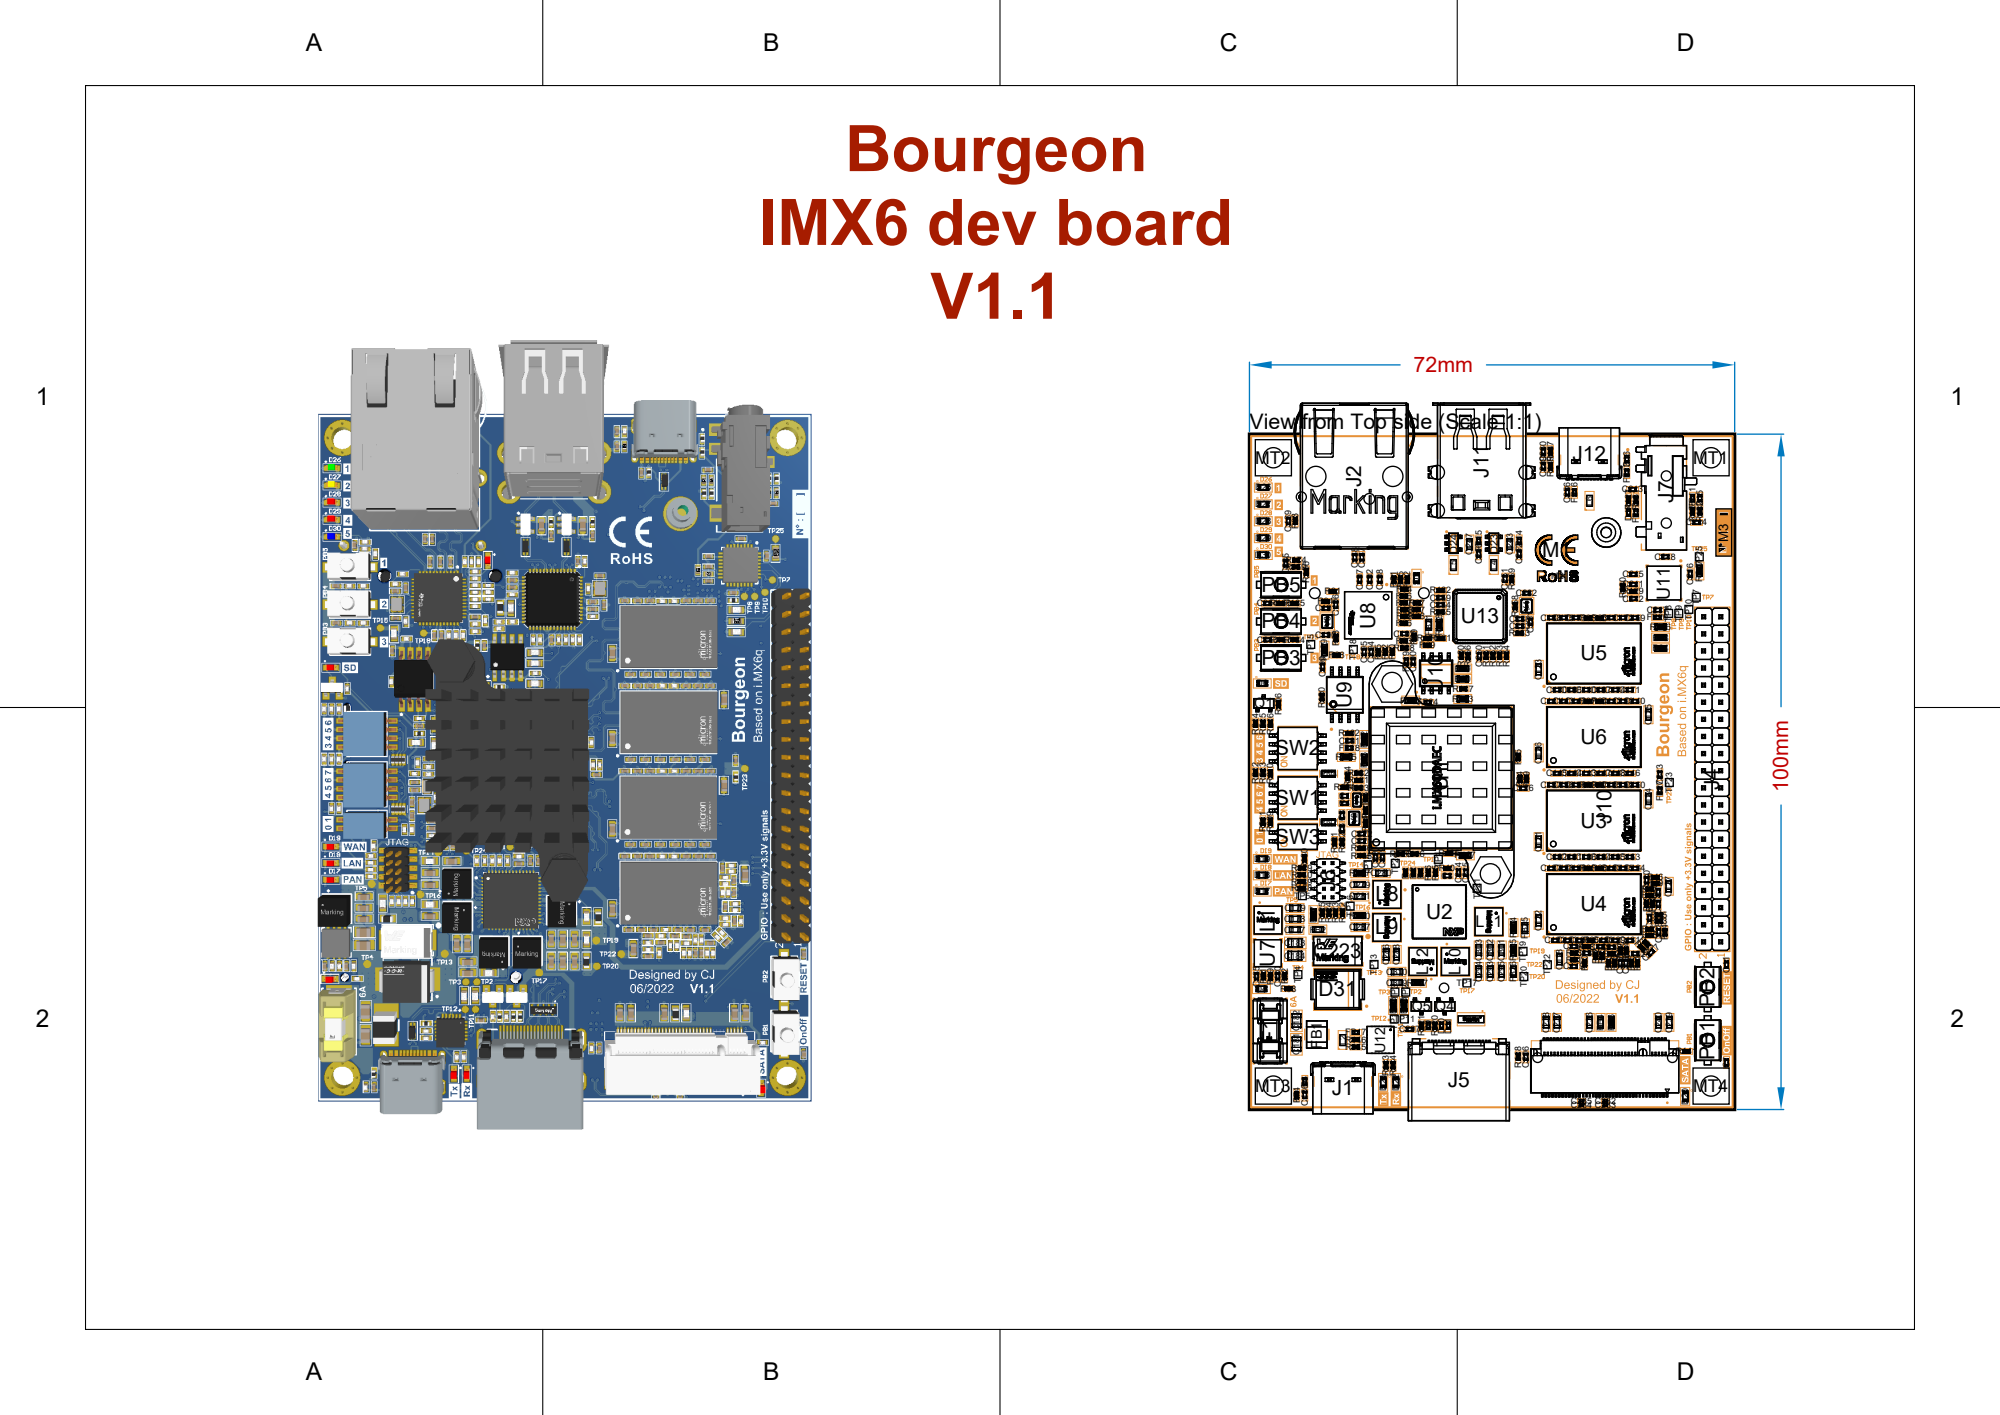
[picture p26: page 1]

View from Top side (Scale 1:1)

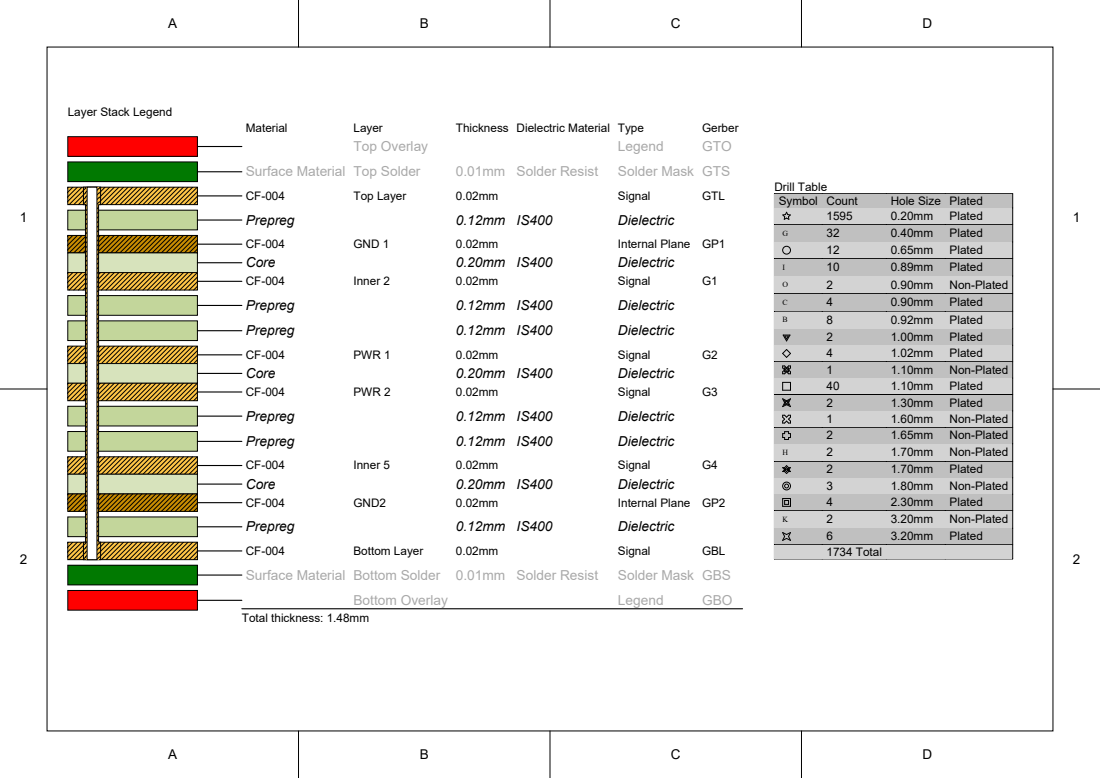
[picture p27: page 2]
Material; Layer; Thickness Dielectric Material Type; Gerber; Top Overlay; Legend; GTO; Surface Material Top Solder; 0.01mm Solder Resist; Solder Mask GTS; Top Layer; Signal; GTL; Prepreg; Dielectric; GND 1; Internal Plane GP1; Core; Inner 2; PWR 1; PWR 2; Inner 5; GND2; Internal Plane GP2; Bottom Layer; GBL; Surface Material Bottom Solder 0.01mm Solder Resist; Solder Mask GBS; Bottom Overlay; GBO; Total thickness: 1.48mm; Drill Table

Layer Stack Legend

Symbol | Count | Hole Size | Plated

1595 | 0.20mm | Plated

G | 32 | 0.40mm | Plated

12 | 0.65mm | Plated

I | 10 | 0.89mm | Plated

O | 2 | 0.90mm | Non-Plated

C | 4 | 0.90mm | Plated

B | 8 | 0.92mm | Plated

2 | 1.00mm | Plated
4 | 1.02mm | Plated
1 | 1.10mm | Non-Plated
40 | 1.10mm | Plated
2 | 1.30mm | Plated
1 | 1.60mm | Non-Plated
2 | 1.65mm | Non-Plated

H | | | 2 | 1.70mm | Non-Plated

2 | 1.70mm | Plated
3 | 1.80mm | Non-Plated
4 | 2.30mm | Plated

K | | | 2 | 3.20mm | Non-Plated

6 | 3.20mm | Plated
1734 Total

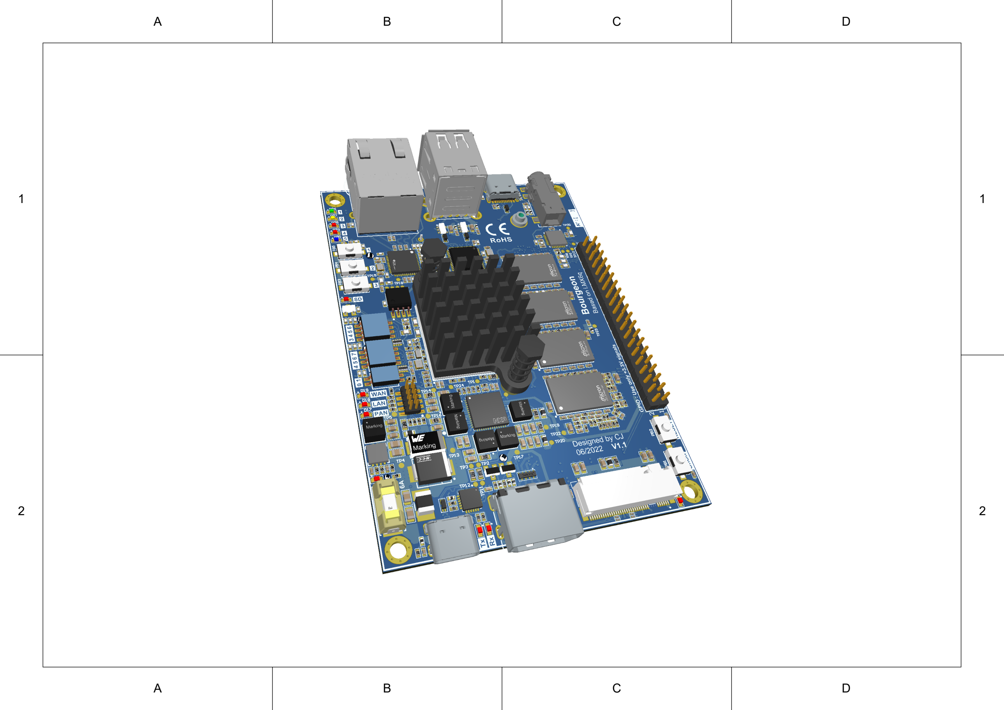
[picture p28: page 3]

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
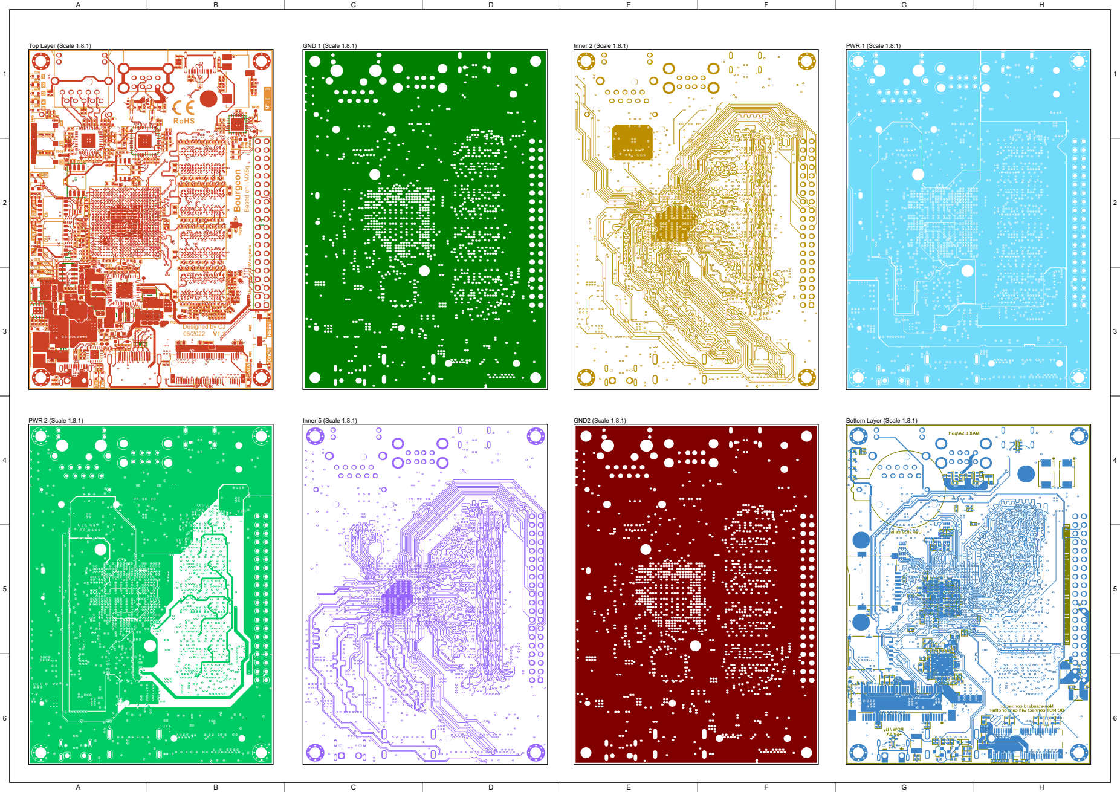
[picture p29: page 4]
PWR 2 (Scale 1.8:1); Inner 5 (Scale 1.8:1); Top Layer (Scale 1.8:1); GND 1 (Scale 1.8:1); Inner 2 (Scale 1.8:1); GND2 (Scale 1.8:1); Bottom Layer (Scale 1.8:1); PWR 1 (Scale 1.8:1)

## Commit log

2023-12-22 add src files
    Altium files and dts/dtb added
    [IMX6 DEV BOARD.PrjPcb, audio_codec.SchDoc, cover_page.SchDoc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]
2023-12-23 add board picture
